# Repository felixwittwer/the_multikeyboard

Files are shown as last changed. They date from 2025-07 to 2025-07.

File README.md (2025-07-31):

<div align="center">



# the_multikeyboard

</div>

A custom keyboard that does it all. Standard keyboard, steno keyboard and macropad. It is a 115% keyboard that is a true alrounder. Besides all the features it excells your typing experience by having a slightly curved shape and some cool wrist rests that attatch magneticaly.

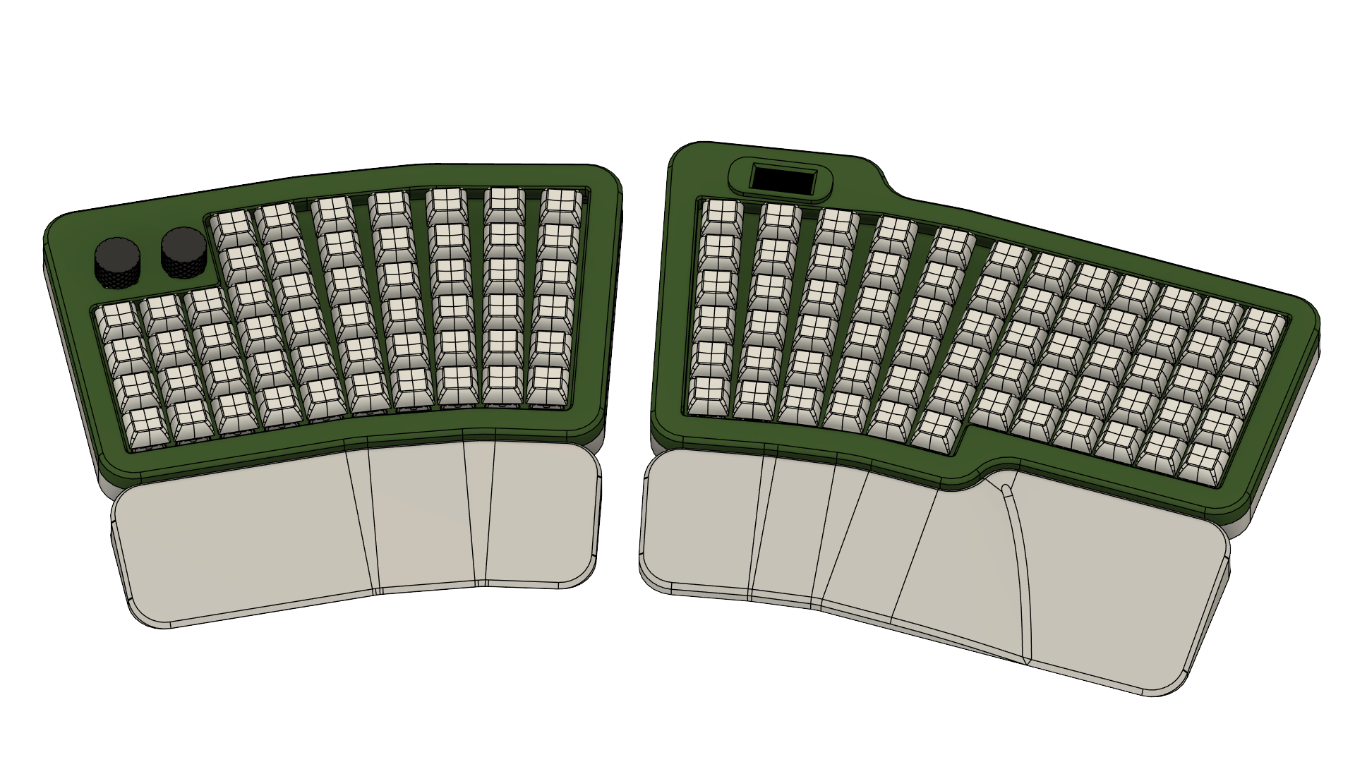
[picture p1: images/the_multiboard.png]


## About the project

I am actually someone that is currently learning steno myself and I already have a matching keyboard for that. Besides I also have a Macropad and of course a normal keyboard. You counted right I have three keyboards on my desk and this is bothering me. Thats why I decided to build my first own custom keyboard that combines all three. **THE MULTIKEYBOARD** is a keyboard that consists of a macropad (on the right side), a full sized keyboard (everything else :]) and a section in the middle that can be used for stenography typing.

[Look at some cool renders ](#renders) 

[... some CAD](#cad)

[... all the nice features](#features)

[... the PCB](#pcb-and-schematics)

[... the firmware](#firmware)

[... all the parst you need (BOM)](#bom)

## The project

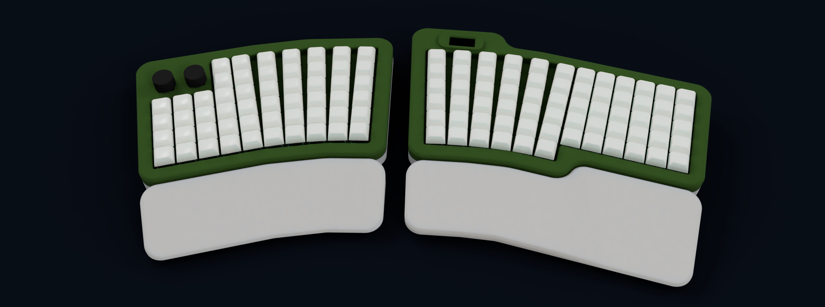
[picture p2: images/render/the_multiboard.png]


### Renders

<p float="left">
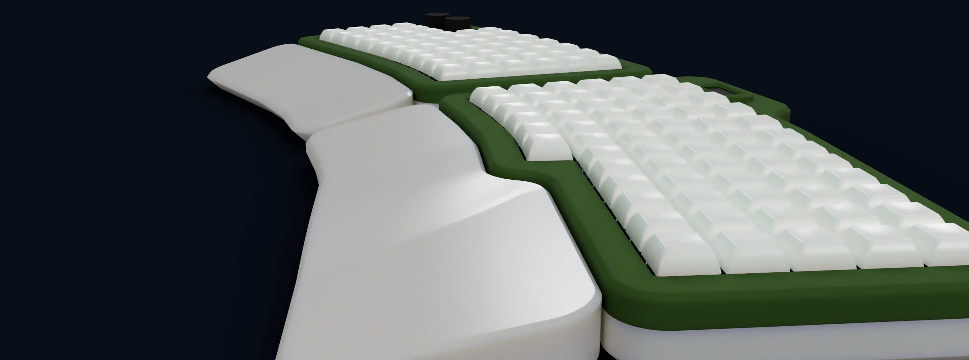
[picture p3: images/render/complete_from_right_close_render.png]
    
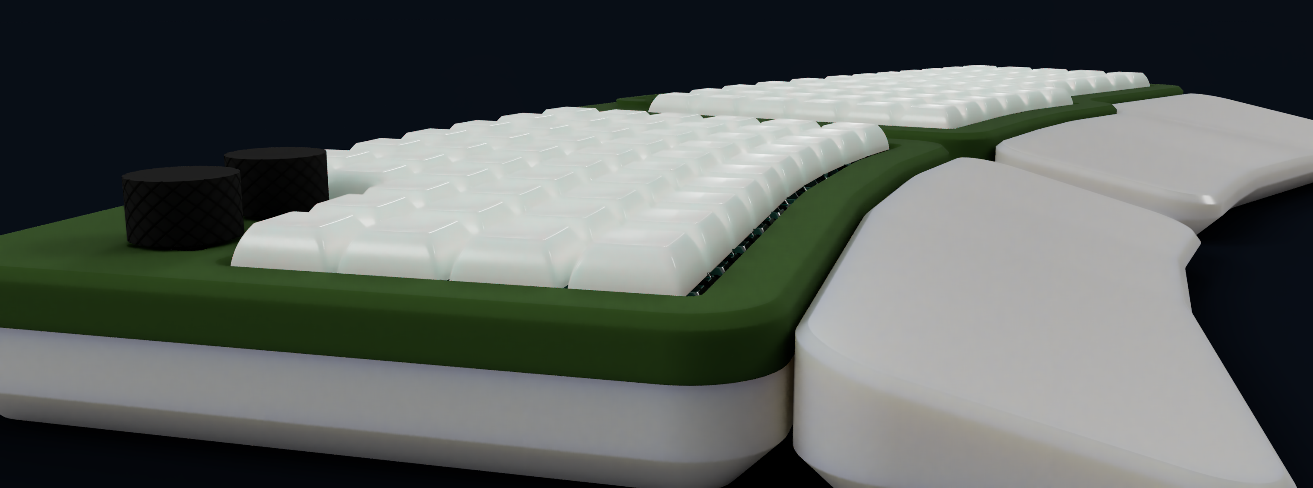
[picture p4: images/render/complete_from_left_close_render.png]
      
</p>
<p float="left">
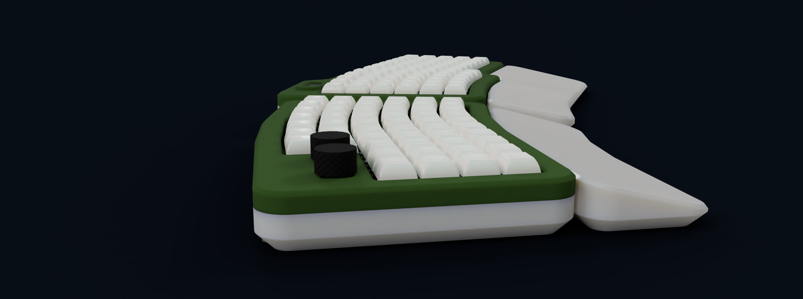
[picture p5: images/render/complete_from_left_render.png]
    
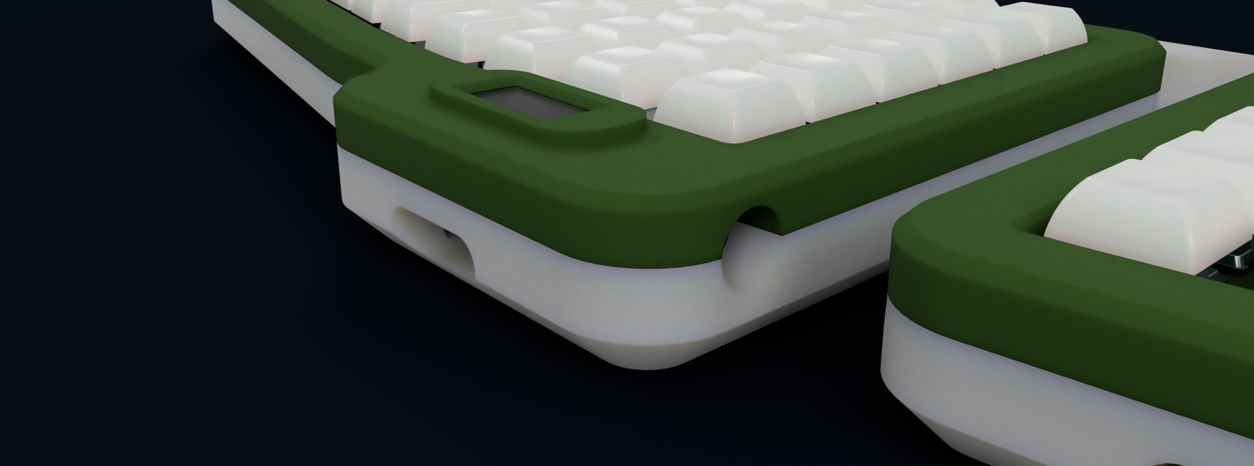
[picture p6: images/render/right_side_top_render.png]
    
</p>
<p float="left">
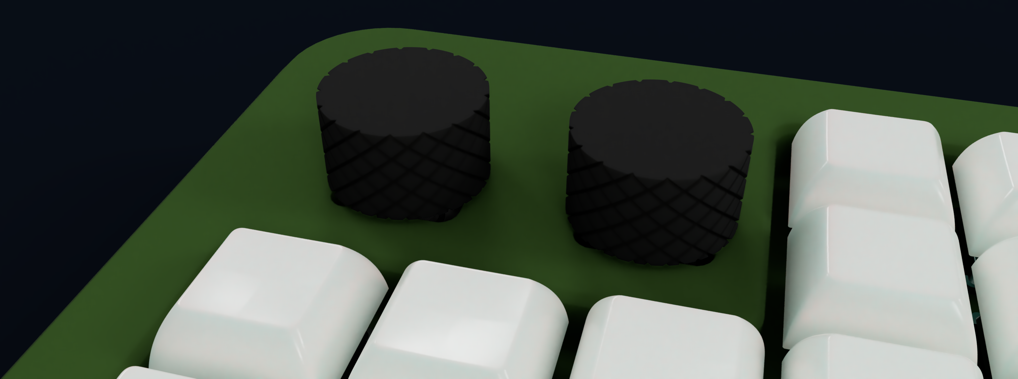
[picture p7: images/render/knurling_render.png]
    
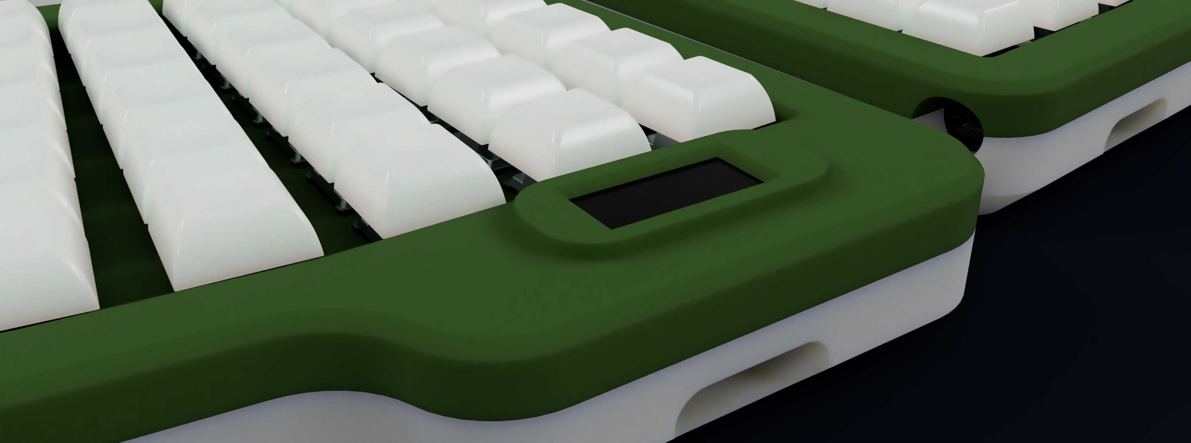
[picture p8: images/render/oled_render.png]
    
</p>

### CAD

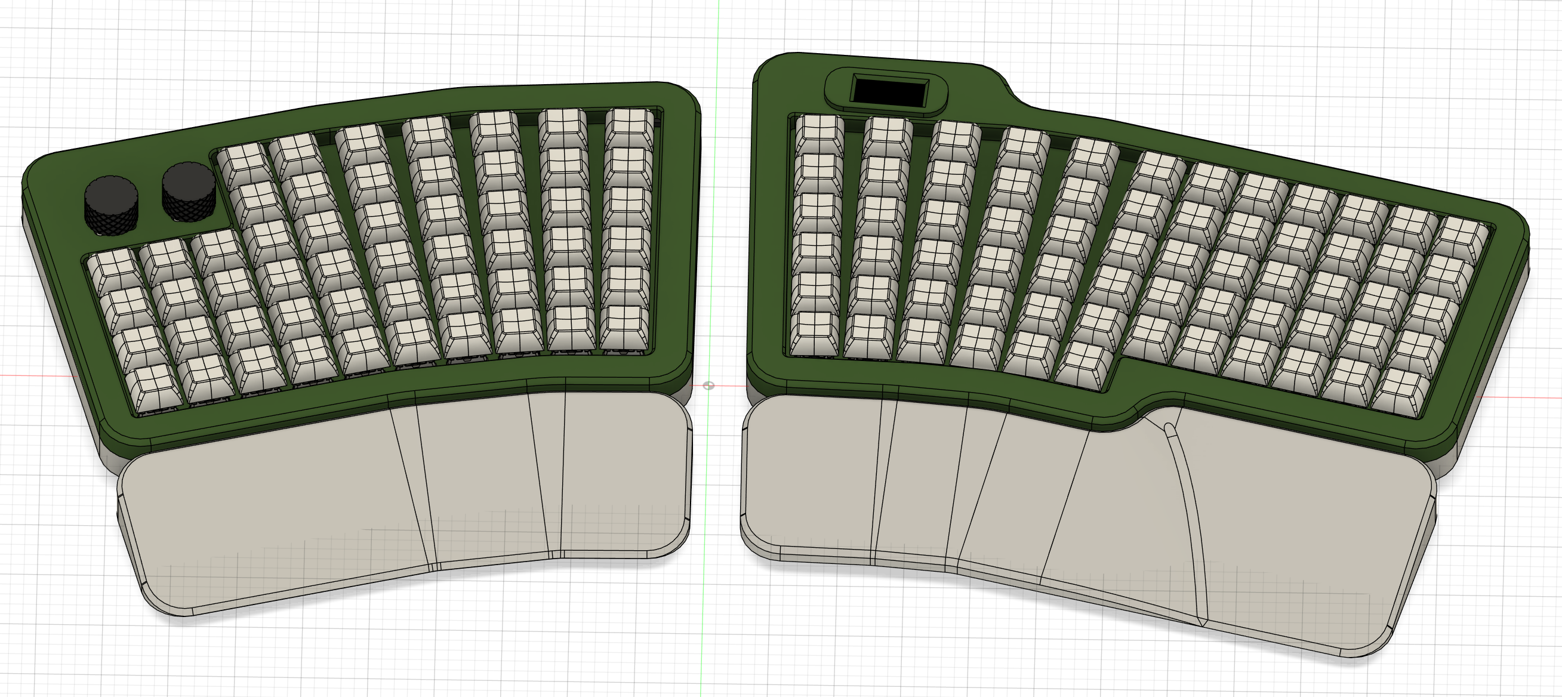
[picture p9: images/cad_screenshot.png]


### Features

**magnetic wrist rest**

Magnets are getting pressed into their location on the keyboard side and get clamped down by the crews holding the top and bottom piece of the keyboard together. On the wrist rest side the magnets just get glued into place. This designvhoice was intentional. I knwo that it is possible to encase magntes by pausing your 3D printer and the resuming but the case is already difficula enough to print due to its size so I don't wanted to add another hurdel.

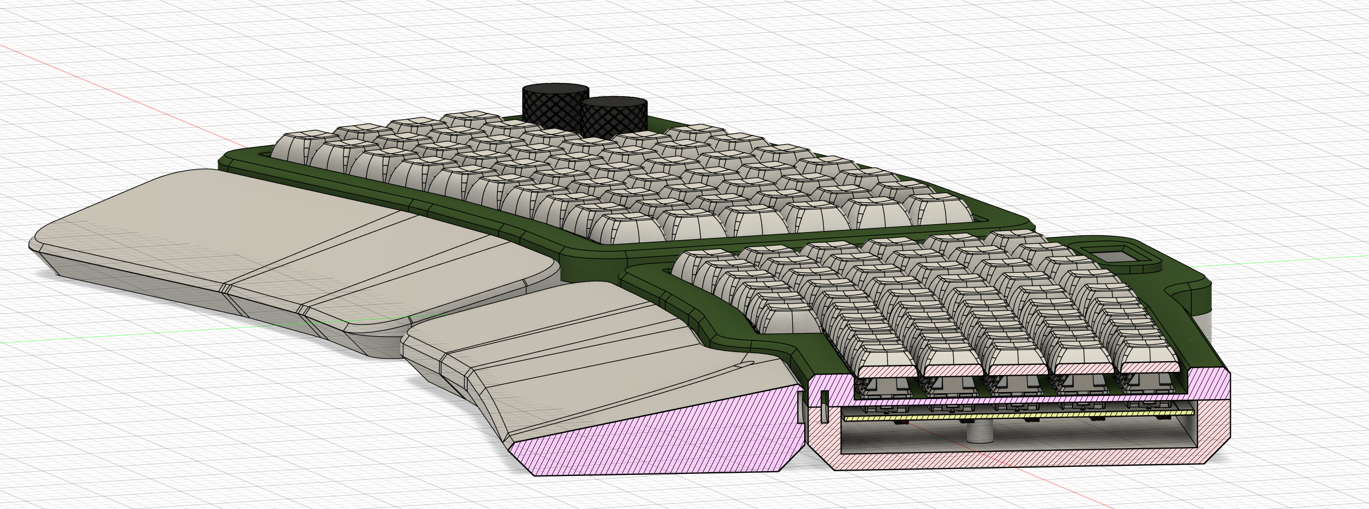
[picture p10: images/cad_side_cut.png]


**OLED**

The keyboard also has a small 0.91" OLED screen that tells you which layer you are currently using. In the future I will maybee add some small pixelart.

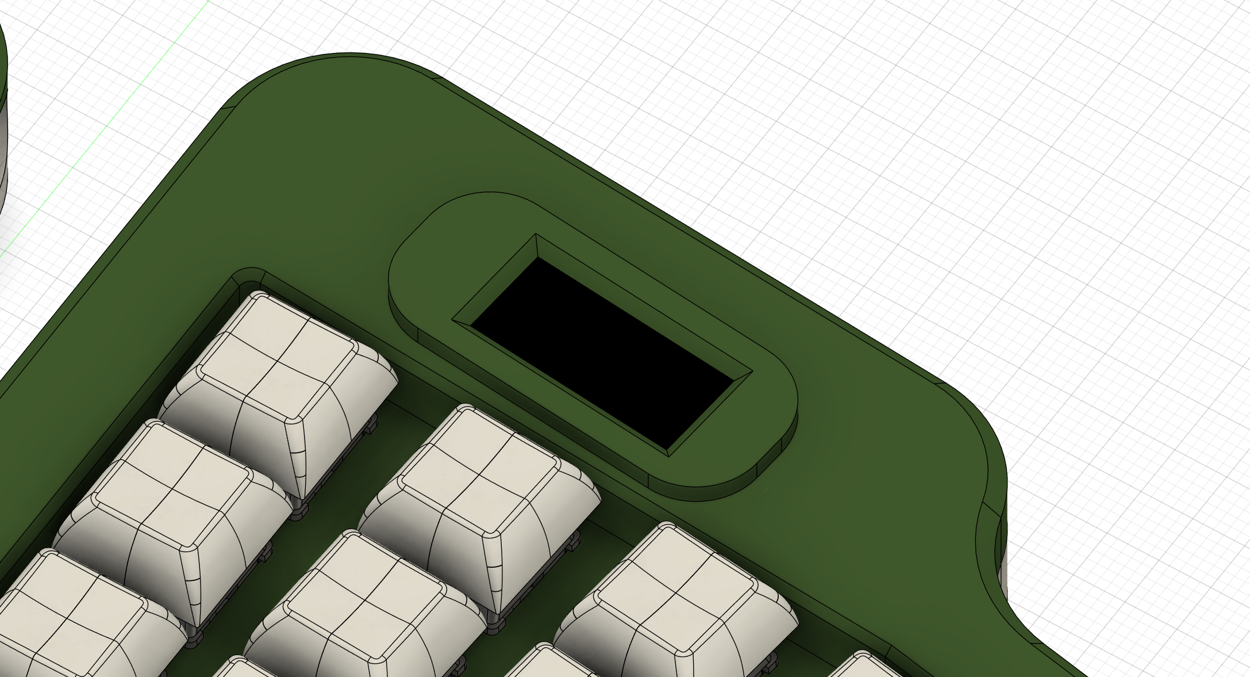
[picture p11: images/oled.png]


**dials with knurling**

The left side of the keyboard is basically a macropad with 16 kustomizable keys and two rotary encoders witha custom dial. The knurling on the dials is probably going to feel amazing.

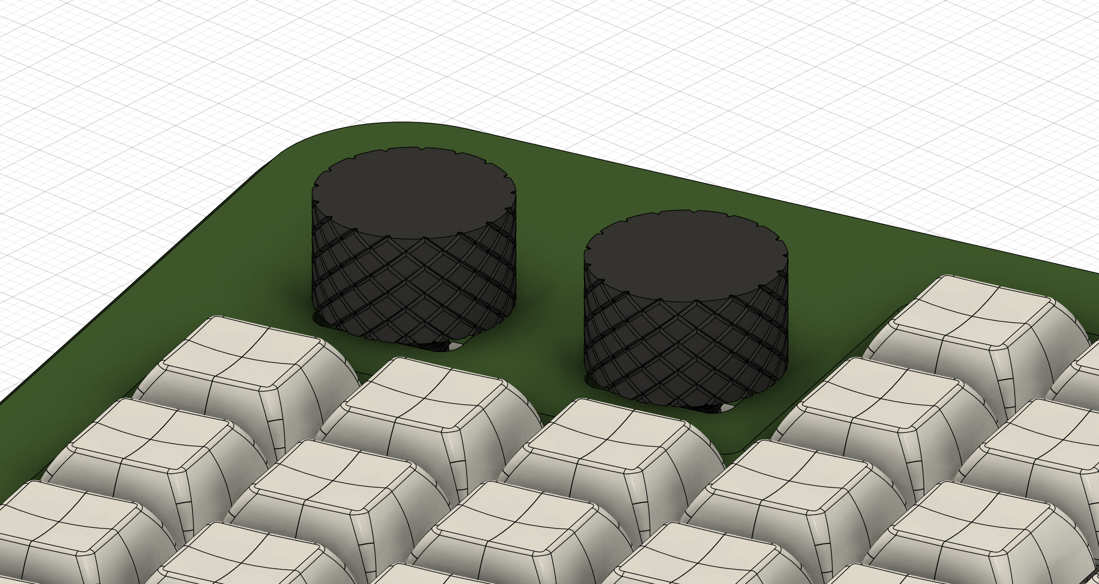
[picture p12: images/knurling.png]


**steno capabilities**

I intentionally designed the kyboard to be steno capable and also have a layout that could fita steno keyboard.

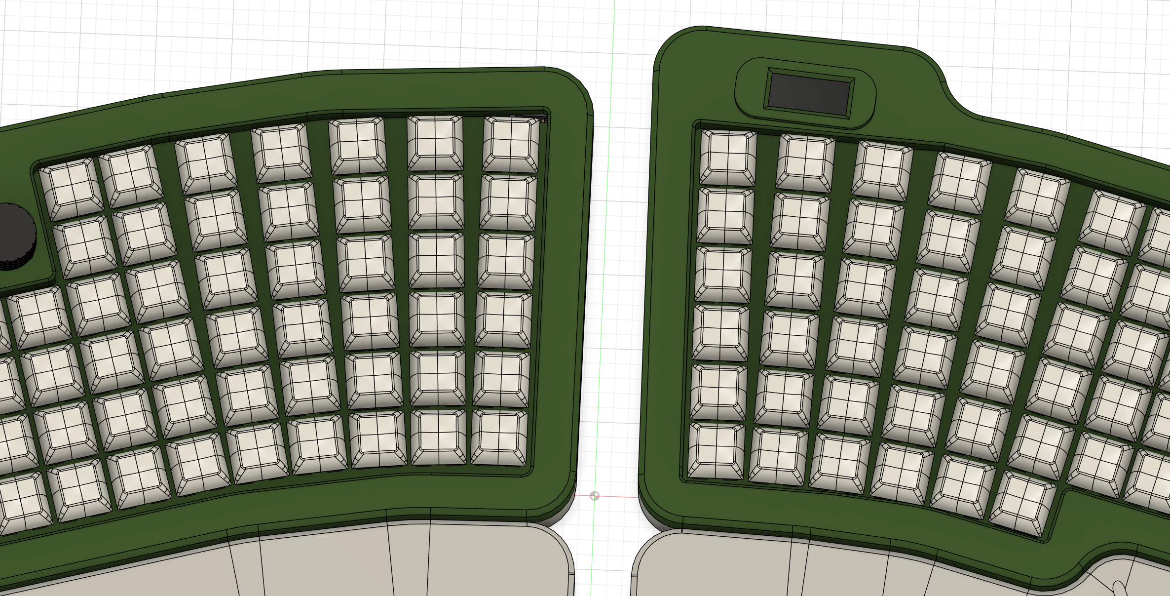
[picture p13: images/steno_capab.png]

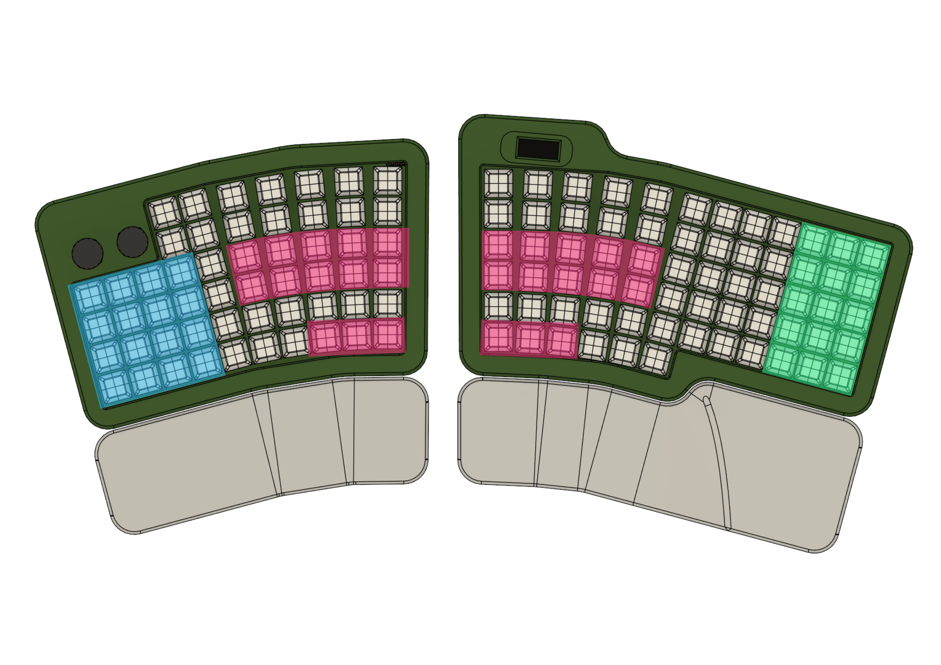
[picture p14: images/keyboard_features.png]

(blue -> macropad, magenta -> steno, green -> numpad)

### PCB and schematics

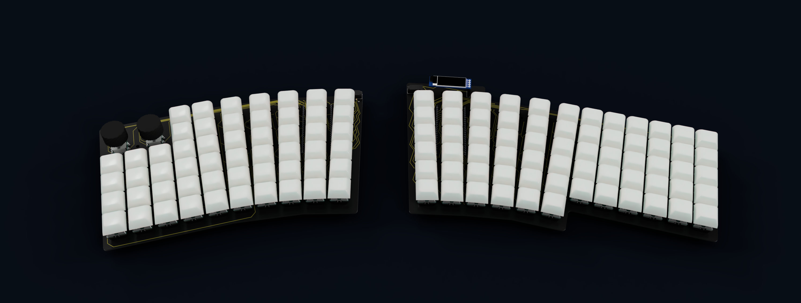
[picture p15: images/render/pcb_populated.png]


<p float="left">
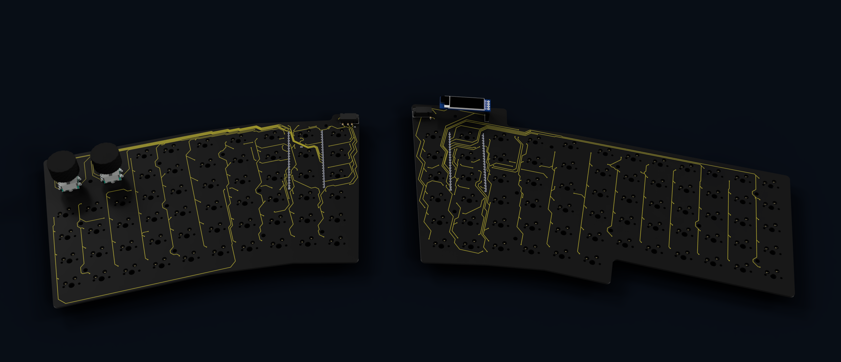
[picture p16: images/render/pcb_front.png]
    
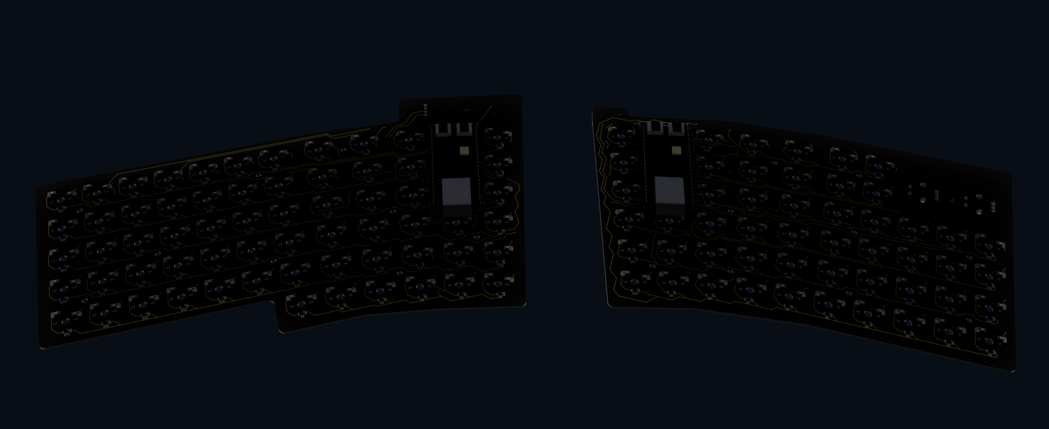
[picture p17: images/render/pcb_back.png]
    
</p>

<p float="left">
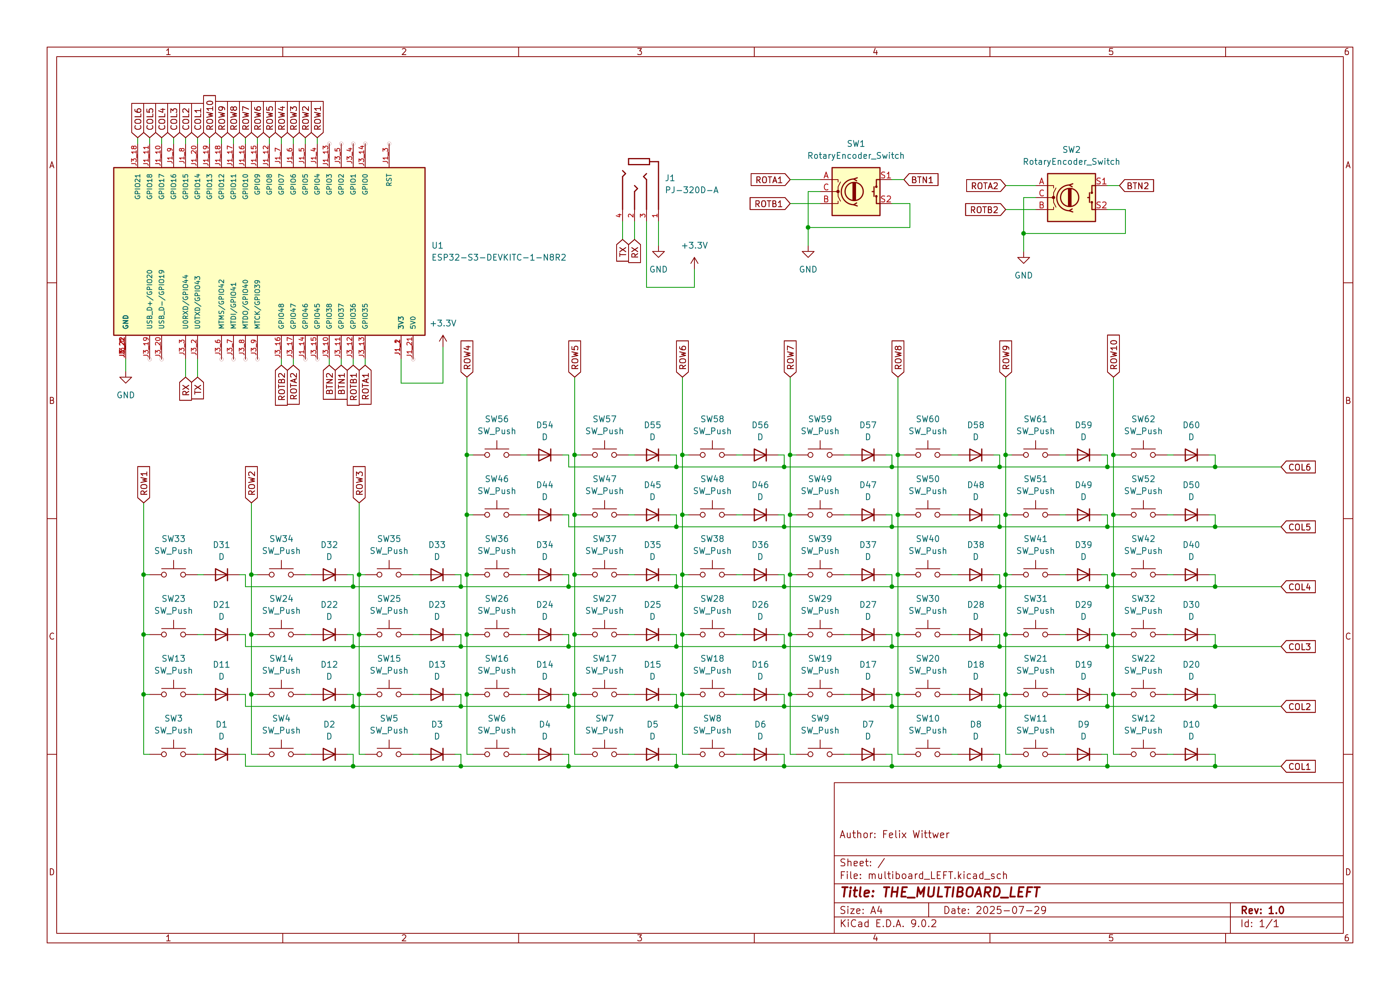
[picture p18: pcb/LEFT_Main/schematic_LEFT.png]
  
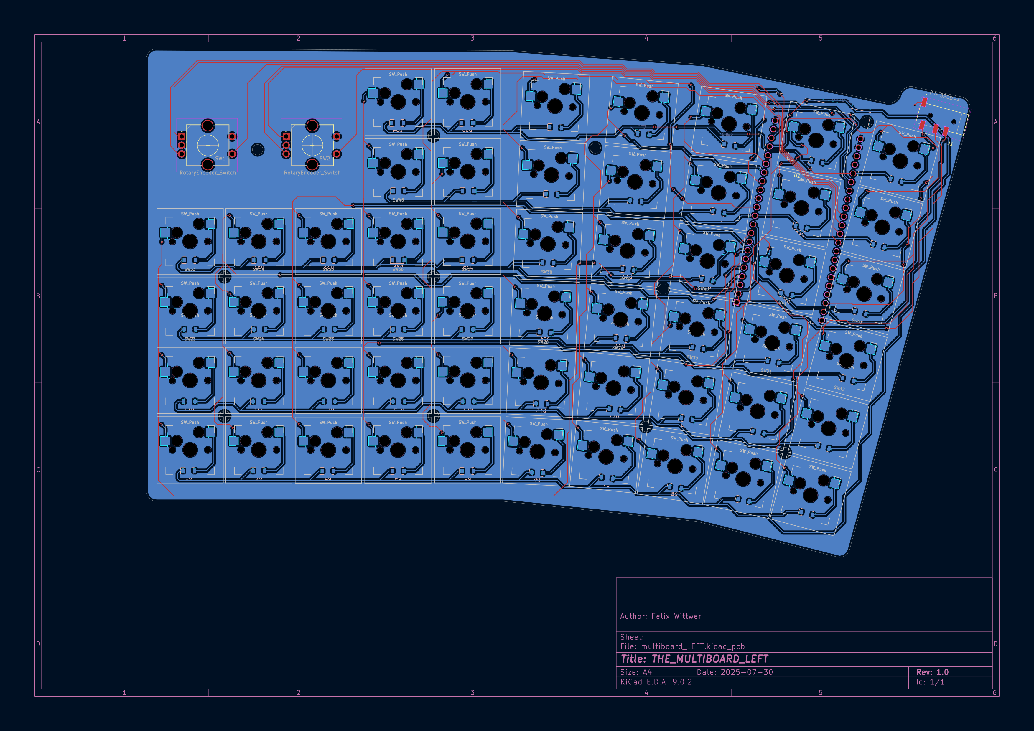
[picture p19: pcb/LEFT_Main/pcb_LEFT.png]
  
</p>

<p float="left">
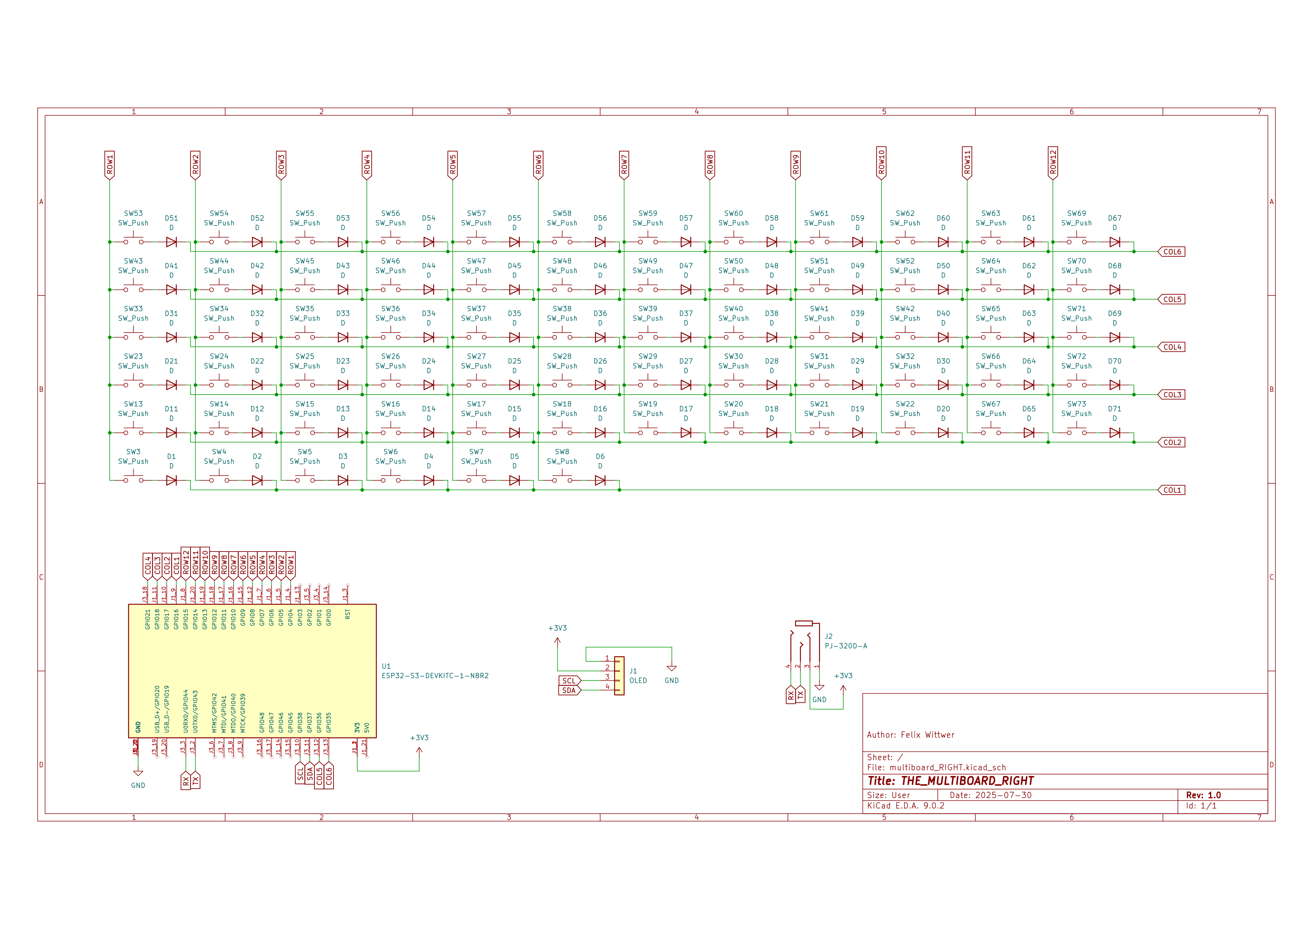
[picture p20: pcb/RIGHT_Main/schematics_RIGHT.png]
  
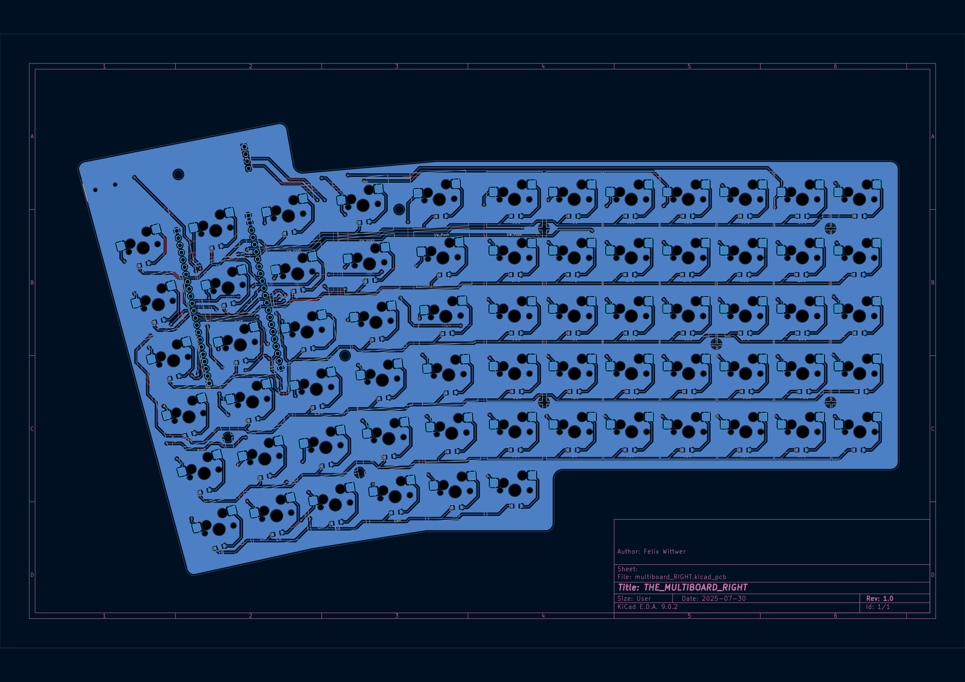
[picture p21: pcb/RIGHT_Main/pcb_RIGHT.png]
  
</p>

## Firmware

The keyboard is running KMK have a look [here](/firmware/).

## BOM

**sum: 79.67 USD**

| part name | amount | price | link | note |
| --- | --- | ----- | ---- | ---- |
| Rotary encoder EC24 | 2 | 1.32 USD | https://de.aliexpress.com/item/1005006894514858.html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 | look out for the EC numer it is importent for the resolution of the encoder 
| Keyswitches | 120 (54+66) | 21.12 USD | https://de.aliexpress.com/item/1005006091988869.html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
| Keycaps | 120 (54+66) | 7.88 USD| https://de.aliexpress.com/item/32842379355.html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 | please look where you can buy matching quantities 120 Keys is larger than normal keyboard size
| hotswap socets | 120 (54+66) | 12.92 USD | https://de.aliexpress.com/item/1005007476614771.html?gatewayAdapt=glo2deu | ---- |
| diodes SOD-123 | 120 (54+66) | 2.74 USD | https://de.aliexpress.com/item/1005004664827360.html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 | ---- |
| headphone jack | 2pcs | 1.16 USD | https://de.aliexpress.com/item/4000661908135.html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 | ---- |
| magnets 10mmx2mm | 8 | 1.16 USD | https://de.aliexpress.com/item/1005009238165372.html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 | ---- |
| ESP32-S3 | 2 | 15.12 USD | https://de.aliexpress.com/item/1005008209644199.html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 | ---- |
| 0.96" OLED | 1 | 1.16 USD | https://de.aliexpress.com/item/1005006153887805.html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 | ---- |
| PCB LEFT Main | 1 | ~ 5 USD |  https://jlcpcb.com/ | price is subject to JLCs review |
| PCB RIGHT BACK | 1 | ~ 5 USD |  https://jlcpcb.com/ | price is subject to JLCs review |
| | total | 74.67 + (shipping ~5 USD) **79.67 USD** | 

**sum: 79.67 USD**

## Credits

**Thanks for the detailed 3D models!**

Gateron keyswitch 3D model: https://www.gateron.com/pages/3d

Keycap 3D model: https://grabcad.com/library/dsa-keycap-for-cherry-mx-switches-1

ESP32-S3 (before I modified it): https://grabcad.com/library/esp32-s3-module-for-pcb-preview-1

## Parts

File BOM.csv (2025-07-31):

part name | amount | price | link | note
Rotary encoder EC24 | 2 | 1.32 USD | https://de.aliexpress.com/item/1005006894514858.html?utparam-url=scene%3Asearch%7Cquery_from%3A | look out for the EC numer it is importent for the resolution of the encoder
Keyswitches | 120 (54+66) | 21.12 USD | https://de.aliexpress.com/item/1005006091988869.html?utparam-url=scene%3Asearch%7Cquery_from%3A
Keycaps | 120 (54+66) | 7.88 US | https://de.aliexpress.com/item/32842379355.html?utparam-url=scene%3Asearch%7Cquery_from%3A | please look where you can buy matching quantities 120 Keys is larger than normal keyboard size
hotswap socets | 120 (54+66) | 12.92 USD | https://de.aliexpress.com/item/1005007476614771.html?gatewayAdapt=glo2deu | ----
diodes SOD-123 | 120 (54+66) | 2.74 USD | https://de.aliexpress.com/item/1005004664827360.html?utparam-url=scene%3Asearch%7Cquery_from%3A | ----
headphone jack | 2pcs | 1.16 USD | https://de.aliexpress.com/item/4000661908135.html?utparam-url=scene%3Asearch%7Cquery_from%3A | ----
magnets 10mmx2mm | 8 | 1.16 USD | https://de.aliexpress.com/item/1005009238165372.html?utparam-url=scene%3Asearch%7Cquery_from%3A
ESP32-S3 | 2 | 15.12 USD | https://de.aliexpress.com/item/1005008209644199.html?utparam-url=scene%3Asearch%7Cquery_from%3A | ----
0.96" OLED | 1 | 1.16 USD | https://de.aliexpress.com/item/1005006153887805.html?utparam-url=scene%3Asearch%7Cquery_from%3A | ----
PCB LEFT Main | 1 | ~ 5 USD | https://jlcpcb.com/ | price is subject to JLCs review
PCB RIGHT BACK | 1 | ~ 5 USD | https://jlcpcb.com/ | price is subject to JLCs review
 | total | 79.67 USD

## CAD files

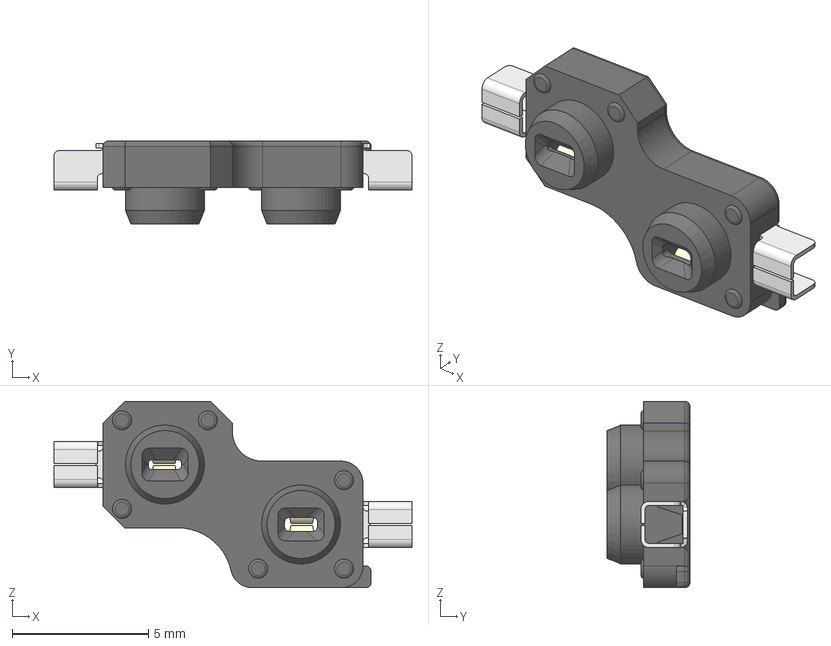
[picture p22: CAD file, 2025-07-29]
pcb/LEFT_Main/multiboard_LEFT/MX_V2-main/3D/Kailh-Choc-Socket-CPG135001S30.step
13.1 x 3.05 x 6.85 mm
Insert 2
Insert 1

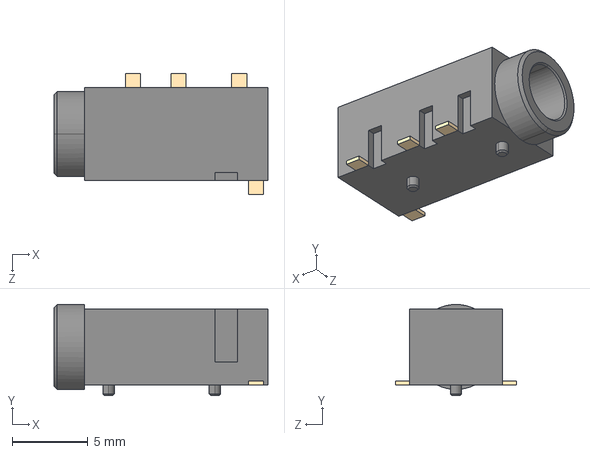
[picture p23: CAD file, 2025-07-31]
pcb/LEFT_Main/multiboard_LEFT/PJ-320D-A/PJ-320D-A.step
14.1 x 6.00 x 8.00 mm

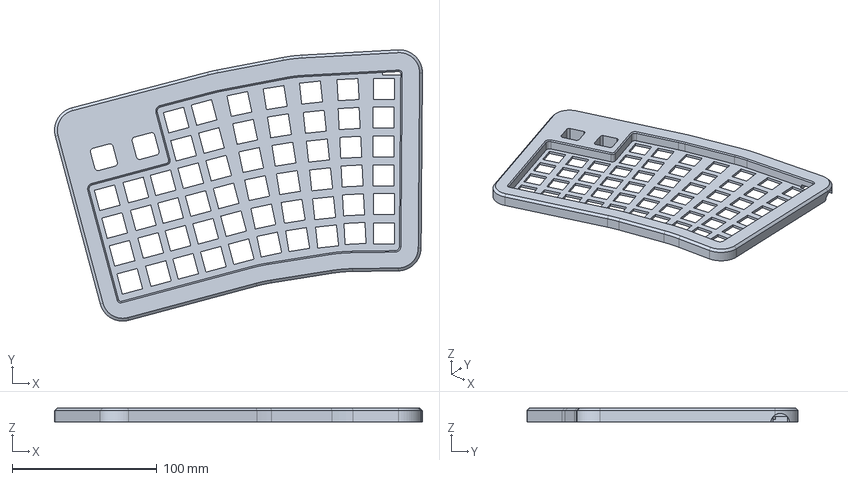
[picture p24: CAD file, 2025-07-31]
production/case/right_top.step
254.2 x 187.5 x 10.0 mm

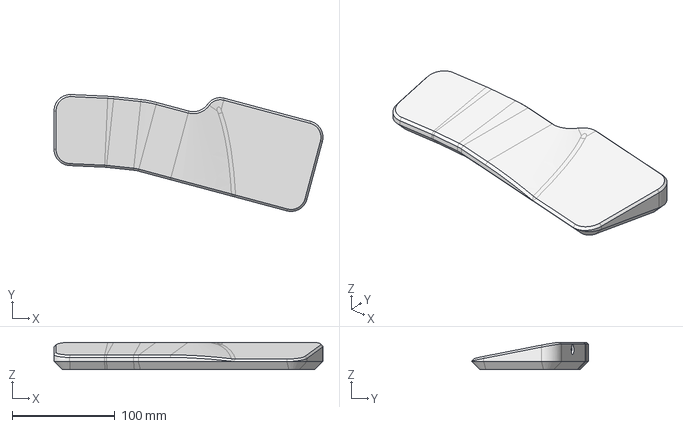
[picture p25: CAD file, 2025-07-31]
production/wrist_rest/right_rest.step
261.2 x 113.5 x 26.6 mm

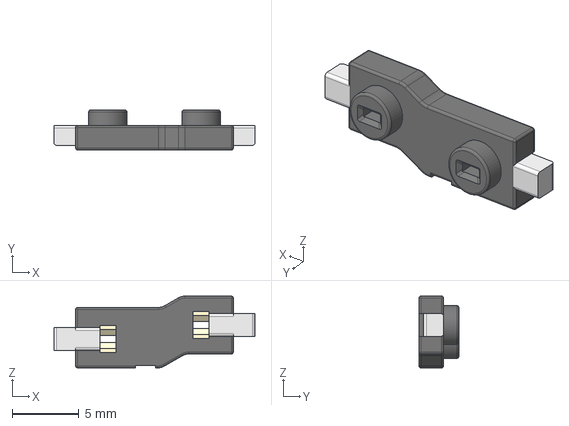
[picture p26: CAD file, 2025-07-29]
pcb/LEFT_Main/multiboard_LEFT/MX_V2-main/3D/Gateron-KS33-Socket.step
15.1 x 3.00 x 5.40 mm

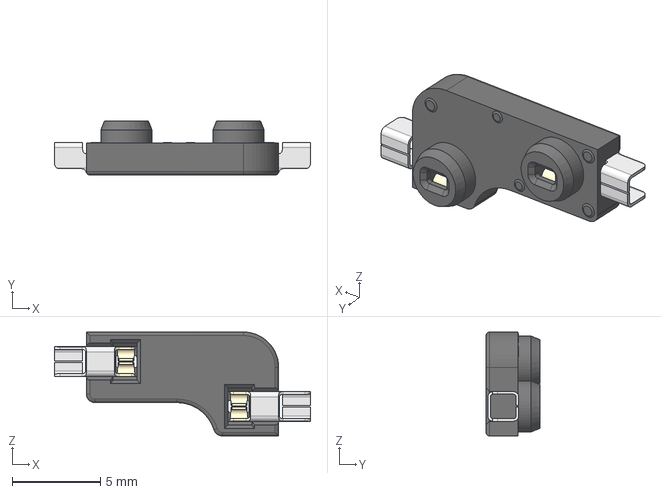
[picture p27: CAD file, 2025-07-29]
pcb/RIGHT_Main/multiboard_RIGHT/MX_V2-main/3D/MX-Hotswap-Socket.step
14.5 x 3.05 x 5.89 mm

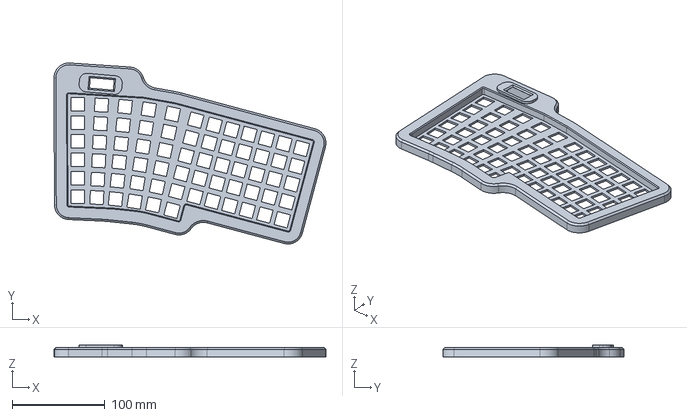
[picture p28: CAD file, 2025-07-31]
production/case/left_top.step
293.1 x 195.1 x 12.5 mm

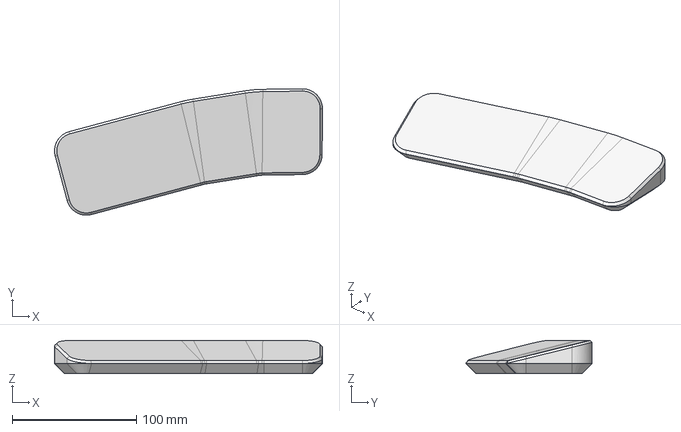
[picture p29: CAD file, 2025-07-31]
production/wrist_rest/left_rest.step
215.4 x 101.6 x 26.5 mm

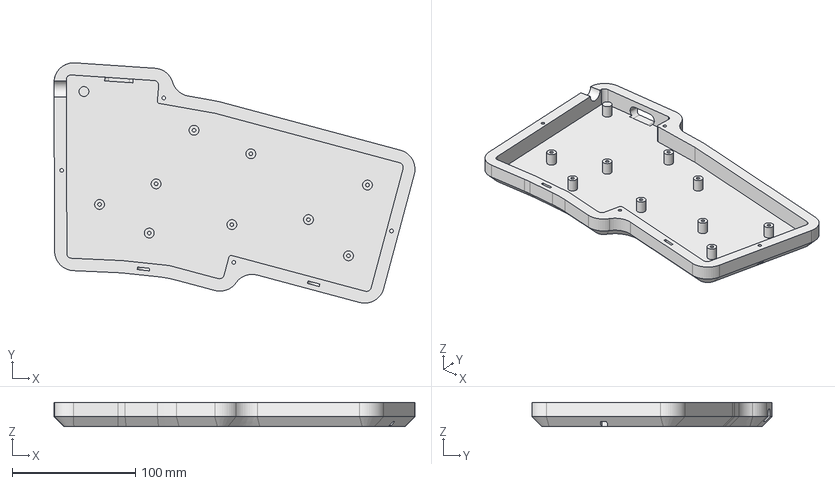
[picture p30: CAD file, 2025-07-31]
production/case/right_bottom.step
293.1 x 195.1 x 19.5 mm

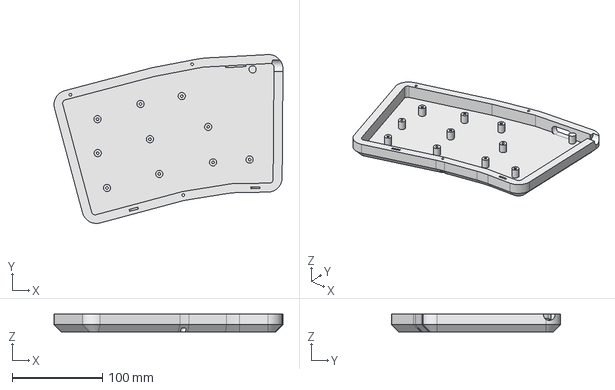
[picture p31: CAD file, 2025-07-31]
production/case/left_bottom.step
254.2 x 187.5 x 19.5 mm

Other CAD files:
production/case/left_bottom.stl
production/case/left_top.stl
production/case/right_bottom.stl
production/case/right_top.stl
production/wrist_rest/left_rest.stl
production/wrist_rest/right_rest.stl

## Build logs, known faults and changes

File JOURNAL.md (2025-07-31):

---
title: "The Multikeyboard"
author: "Felix Wittwer (fegolix)"
description: "A split keyboard that can be a keyboard, macropad and steno keyboard at the same time"
created_at: "2024-07-29"
---

# Journal

Here you can see a documentation of the entire development process.

**Total hours spent: 25h**

## July 29th (4h)

### Session 1 (2h) planing and layout

As a starting point for my custom split keyboard I decided to take some rough measurements of my hand an arrange the keys over it inside Inkscape. I decided on going with a full sized layout with the addition of a macropad and two rotary encoders on the left side. As someone who is coding on a daily bases it was important for me to have a full sized Layout and all the functions keys. If I decide that I do not need the numpad on the right side it can be easealy turned into a second macropad as on the left. For the microcontroler I decided on going with two ESP32-S3s because I use them a lot and they are relatively cheap. Besides that most dev boards also provide two USB ports so I can link them together in teh future via a simple USB C cable. I mean the plan is wireless but to make it futureproof. Pesides that I have lots of GPIO and enough computational power for running the firmware. (Plover for Steno might not be that easy to integrate)

<p float="left">
  
  
</p>

### Session 2 (2h) schematics LEFT

I now started creating the schematics for the LEFT side. Schematic is now done and I can start with designing the PCB. I think it is probably smart to design the PCB for the left side first and the copy the PCB and use it for the right side. So later on I only need to make few changes to the schematic and the PCB is almost finished for the right side. I will probably need to make 4 PCBs or more to also be like the front and backplate of the keyboard. The housing then will be pretty minimal. I mean I kind of like the look of it but we will see.



## July 30th (10h)

### Session 1 (4h) creating left PCB

Getting everything placed where I wanted took some time and until now I also havent fogured out how to rotate multiple elements in KiCad with a specific angele so rotating stuff also took a while :). Due to rotating the footprints for the keyswitches I was also abte to fit the ESP on teh back side of the board without needing to make the PCB even bigger than it already is.

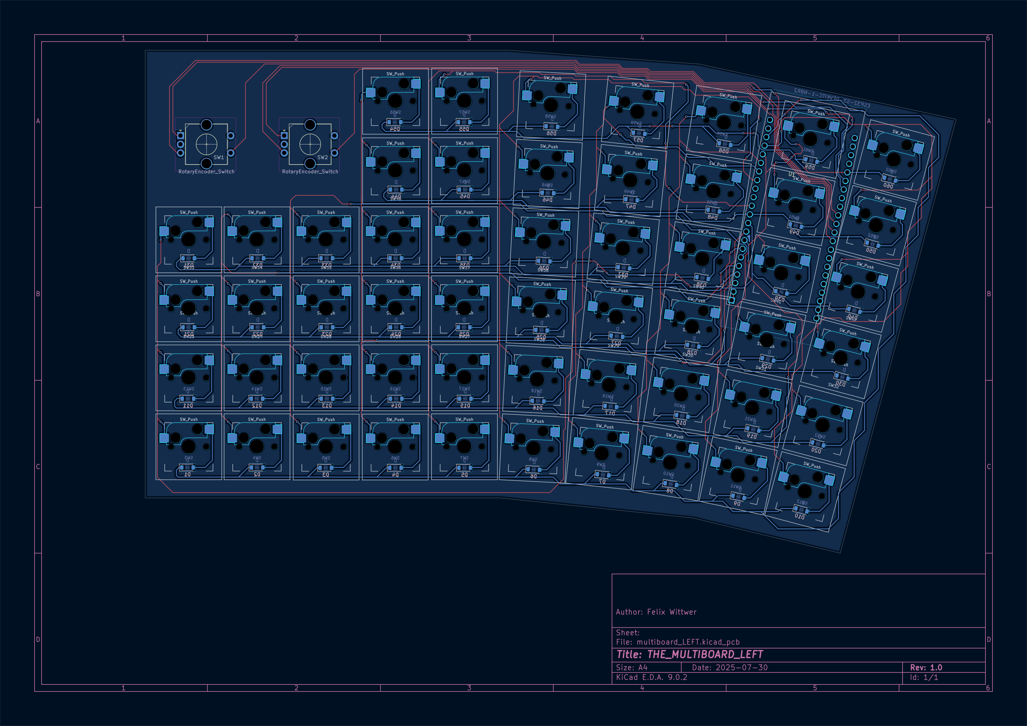
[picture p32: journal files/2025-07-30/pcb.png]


### Session 2 (6h) finishing left and right main PCBs

I have now succesful finised creating the left and right PCBs. I was actually speedrunning the right side until I noticed that the ESP32 was wrongly mirrored so I needed to redo most of the routing. So in the end it took almost the same thime even a bit longer that the left side. Because my PCBs are relatively large I am not going to design a 3D printed housing becuse it somply wouldn't fit into my 3D printers build volume. I am instead going for a PCB "sandwitch" wit three PCBs per side. The main ones are already finished but I now need backplates and a front plate that is also going around the keyswitches.

<p float="left">
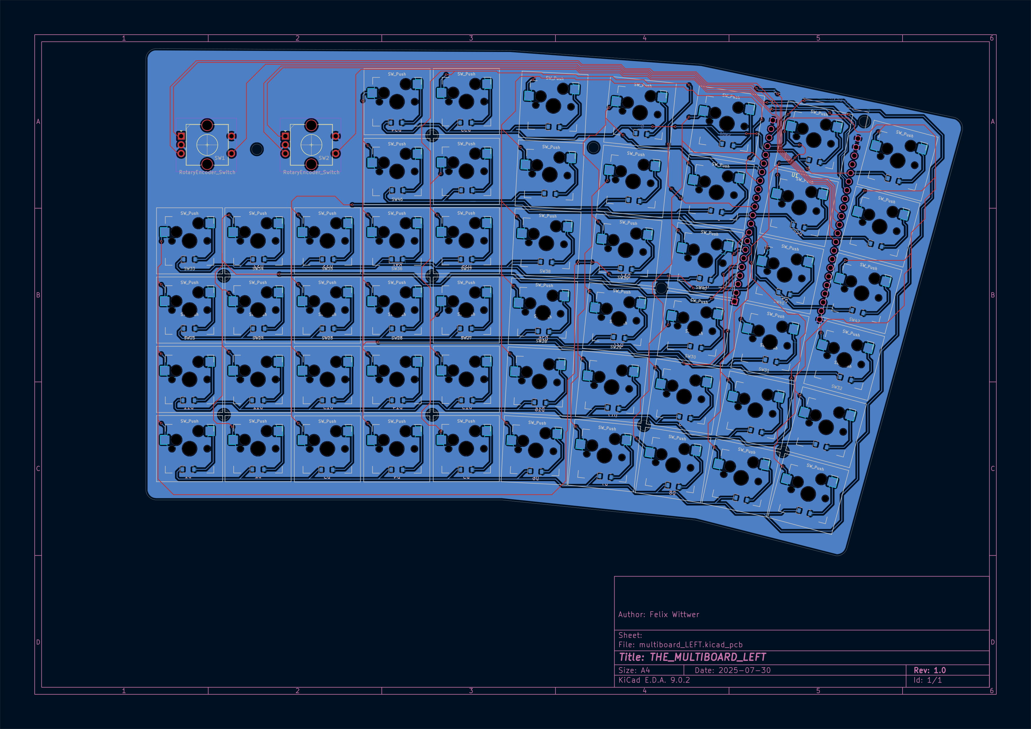
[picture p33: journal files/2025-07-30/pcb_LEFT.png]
  
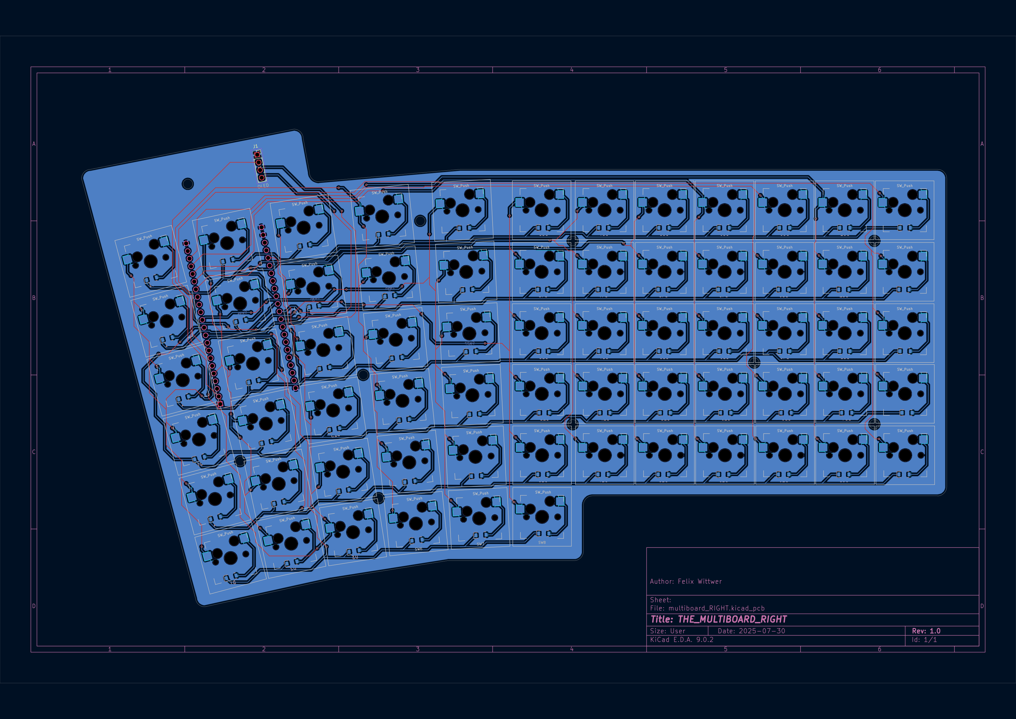
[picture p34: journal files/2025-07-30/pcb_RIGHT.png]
  
</p>

<p float="left">
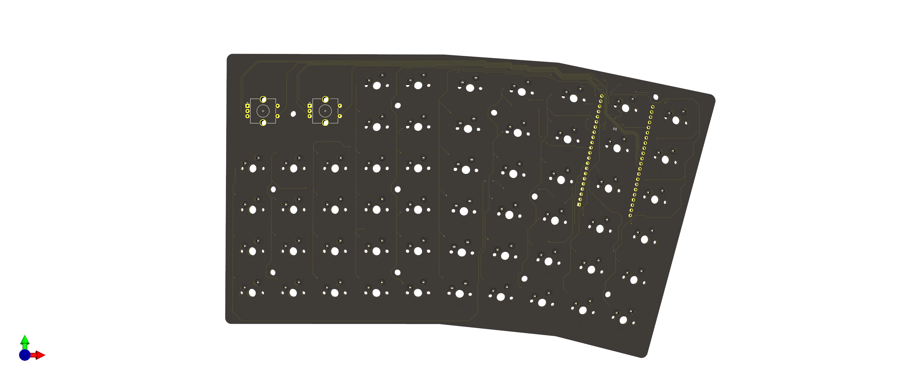
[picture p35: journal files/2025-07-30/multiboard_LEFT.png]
  
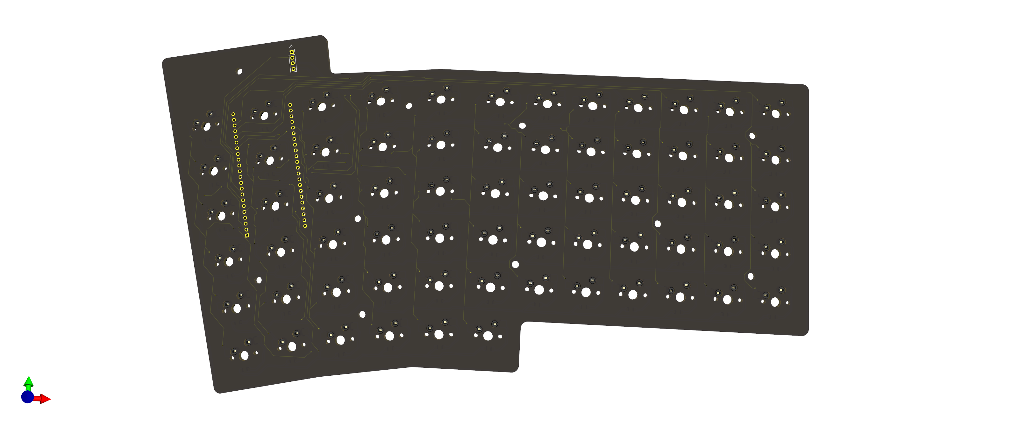
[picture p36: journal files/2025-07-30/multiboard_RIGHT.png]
  
</p>

### Session 3 (30m) researching parts, creating BOM

I have just finished reasearching some parts and searching for cheap components on Aliexpress. I also had the idea of actually doing two seperate design cause the case is probably getting really big and not everybody has a printer with such a buildvolume at home.

## July 31st (6h)

### 

Finally finished with designing the case and placing all the components of the keyboard where they belong. Placing 120 keyswitches wasn't the best task in the world but at least in some areas I could arrange them in a normal rectengular grid. To make my keyboard a bit more special I decided to add some handrests which attach magnetically. I designed it in such a way that the magntes can bee added after printing the case so that you dont have to stop your print in insert them but rather do that later.

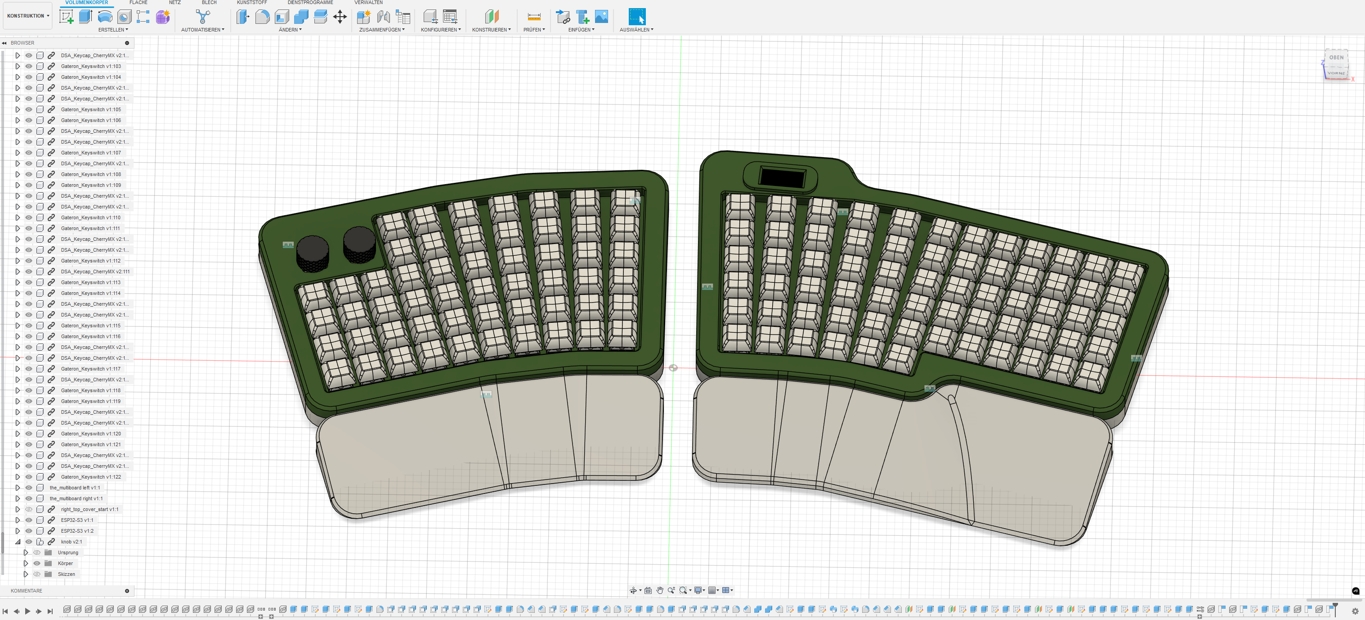
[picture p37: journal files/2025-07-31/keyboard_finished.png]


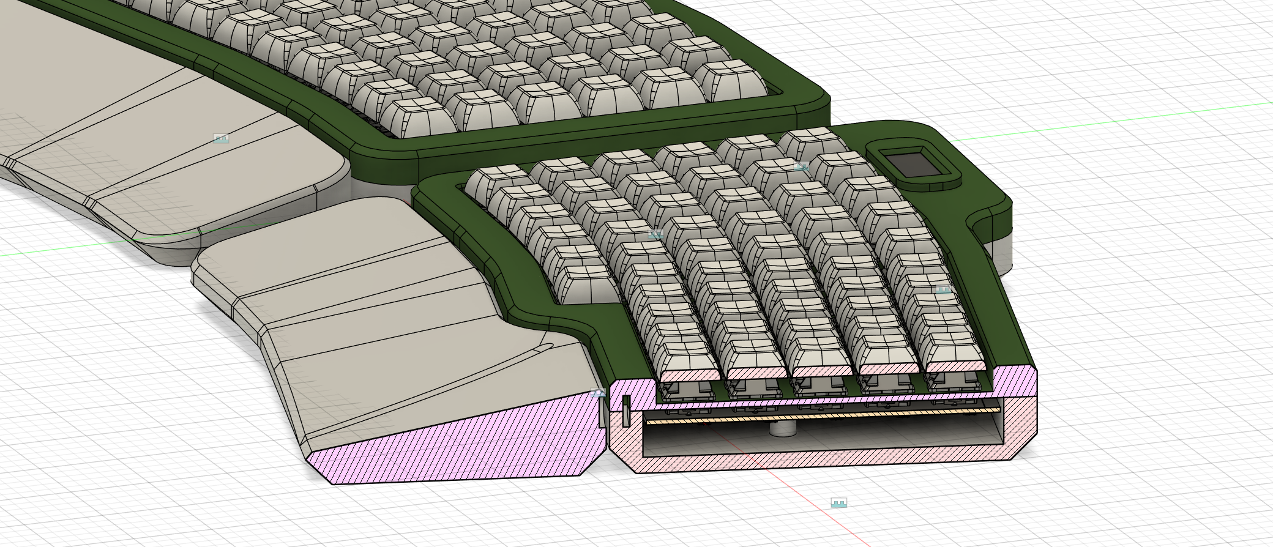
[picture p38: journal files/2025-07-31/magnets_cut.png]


### Session 2 (3h) firmware time

I decieded on going with KMK because it is realatively simpe and also supports steno. So it is perfect for my project. 

Writing the actual firmware turned out to be a bit more diffcult than I thought because I have multiple layers on the ekyboard and steno isnT# usual on most keyboards. besides that I also needed to integrate the macro functionality on the left side.

As of now there will be one key near the macro part that toggles between normal and steno mode. I also noticed that using the second usb port of the esp32-S3 isn't uspported by KMK natively so I need to modify the PCB a bit to have somethign like a beadphone jack to connect both sides via uart.

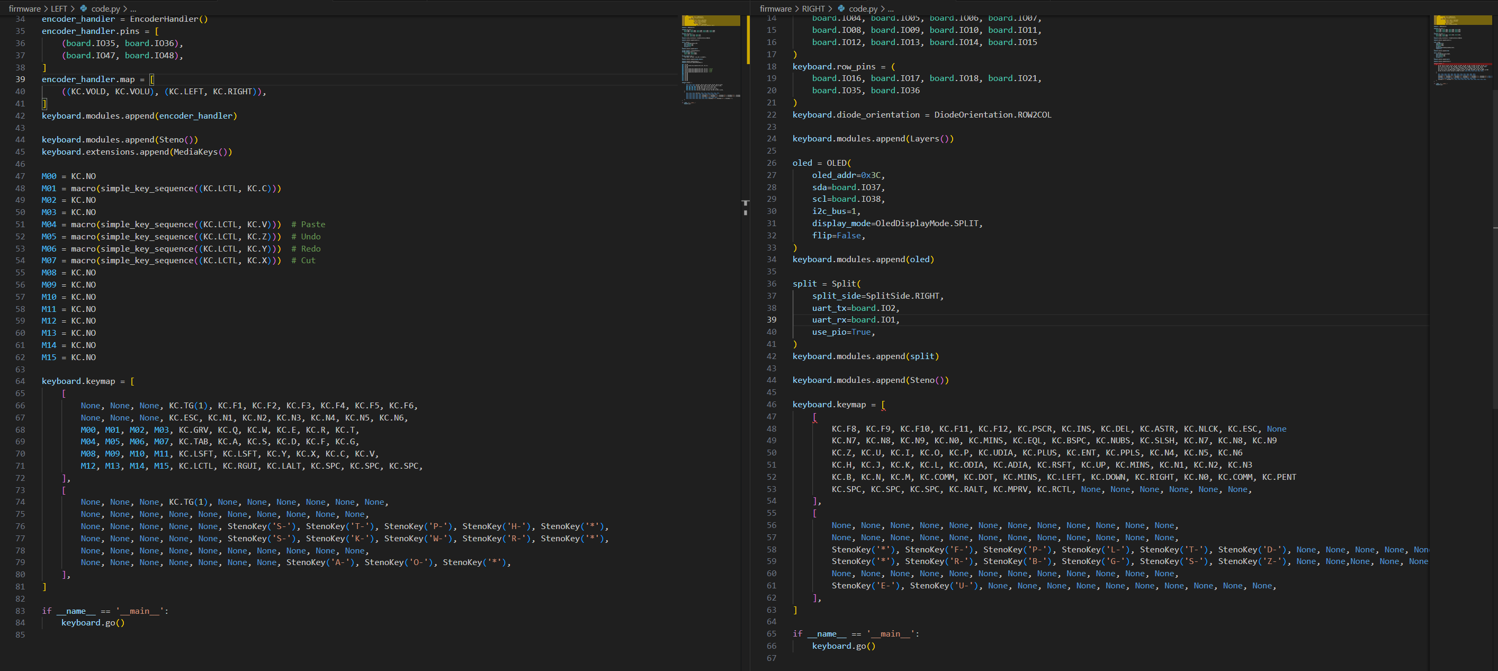
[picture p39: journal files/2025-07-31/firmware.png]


### Session 3 (1h 30m) fixing the pcbs and cad

Adding a headphone jack wasn't as straigtforward as I though. First of all I needed to find matching schematics and also wanted to keeb the PCB shape the same so I don't have to do much ework on the case say so there needed to be done something on the shape.

In the end a got it working and got it also integrated into my existing CAD model. I think it looks got for beeing retrofited afterwards.

<p float="left">
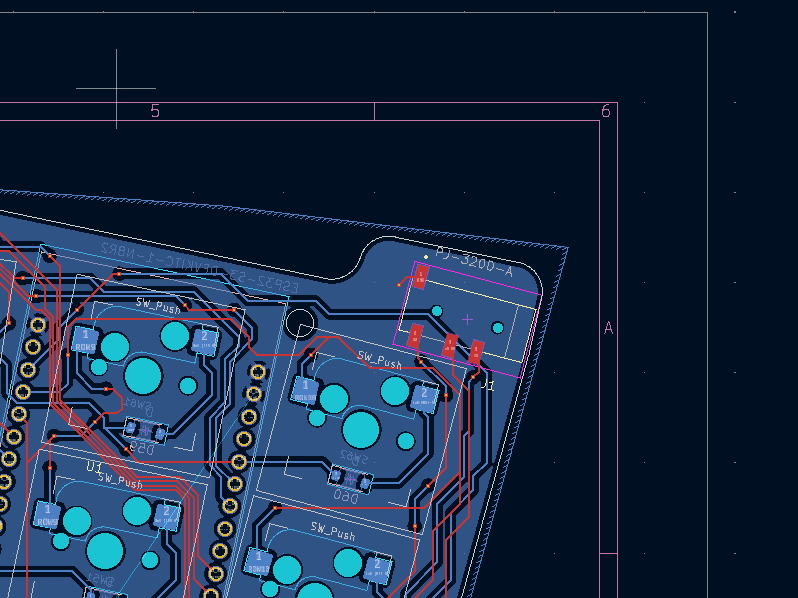
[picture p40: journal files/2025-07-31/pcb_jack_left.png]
  
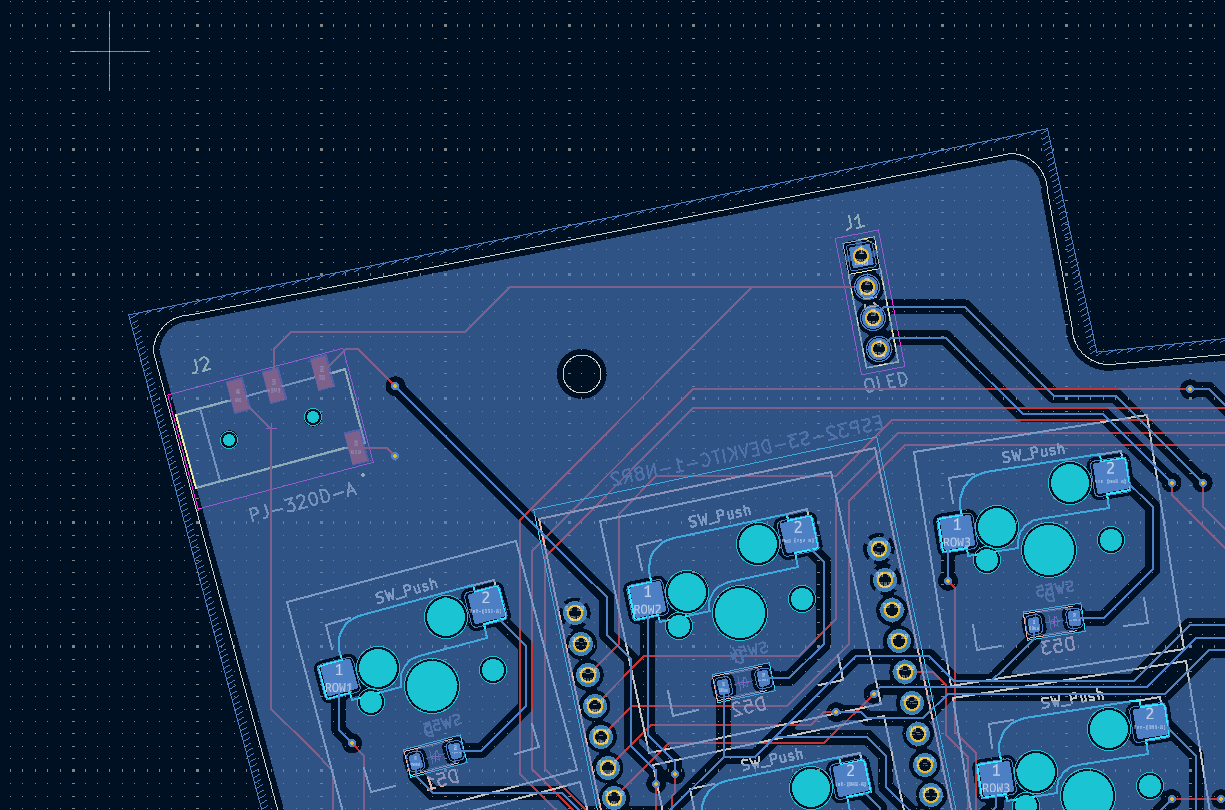
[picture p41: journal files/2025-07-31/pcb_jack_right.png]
  
</p>

<p float="left">
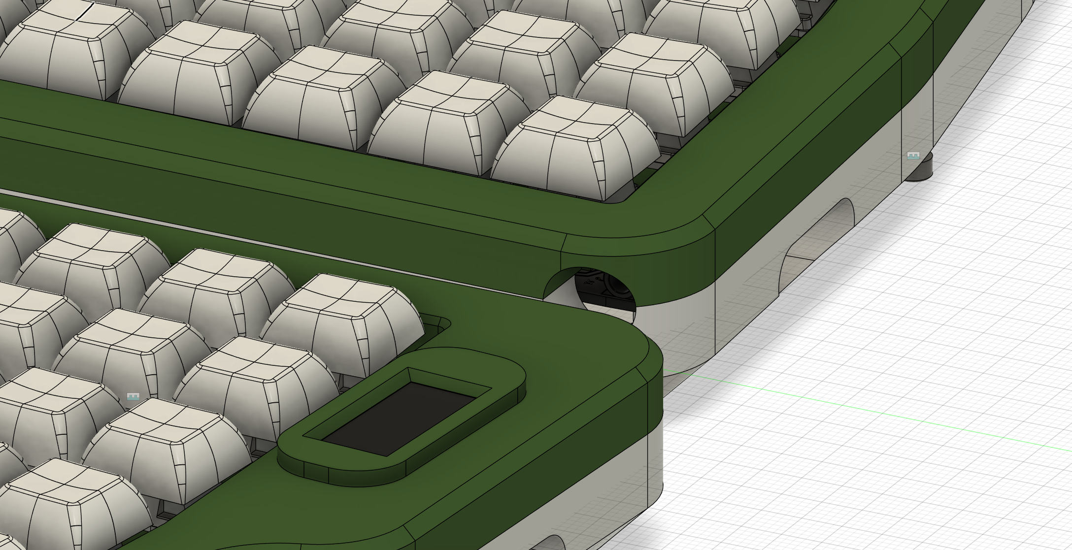
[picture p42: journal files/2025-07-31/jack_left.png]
  
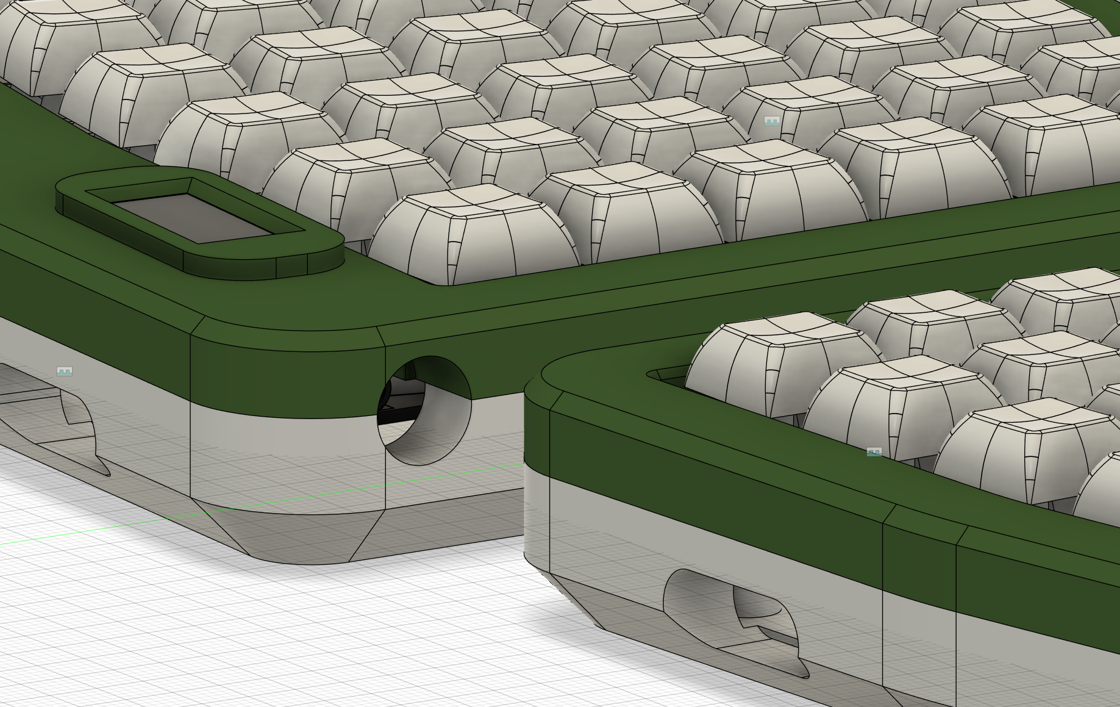
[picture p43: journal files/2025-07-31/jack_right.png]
  
</p>

### Session 4 (1h) finalising firmware, creation production files

The last step now was to recheck everything and create the required files for production. Besides that the project als need to fullfill the hackclub requirements for a submission. I also decided to make some cool renders to show off my keyboard that took so long to desing. Rotation the footprints in KiCad was anabsolute nightmare.

Besides all of that I think I can submit my project now. I have check multiple times if I have everything.

<p float="left">
  
    
</p>
<p float="left">
  
  
</p>
<p float="left">
  
  
</p>

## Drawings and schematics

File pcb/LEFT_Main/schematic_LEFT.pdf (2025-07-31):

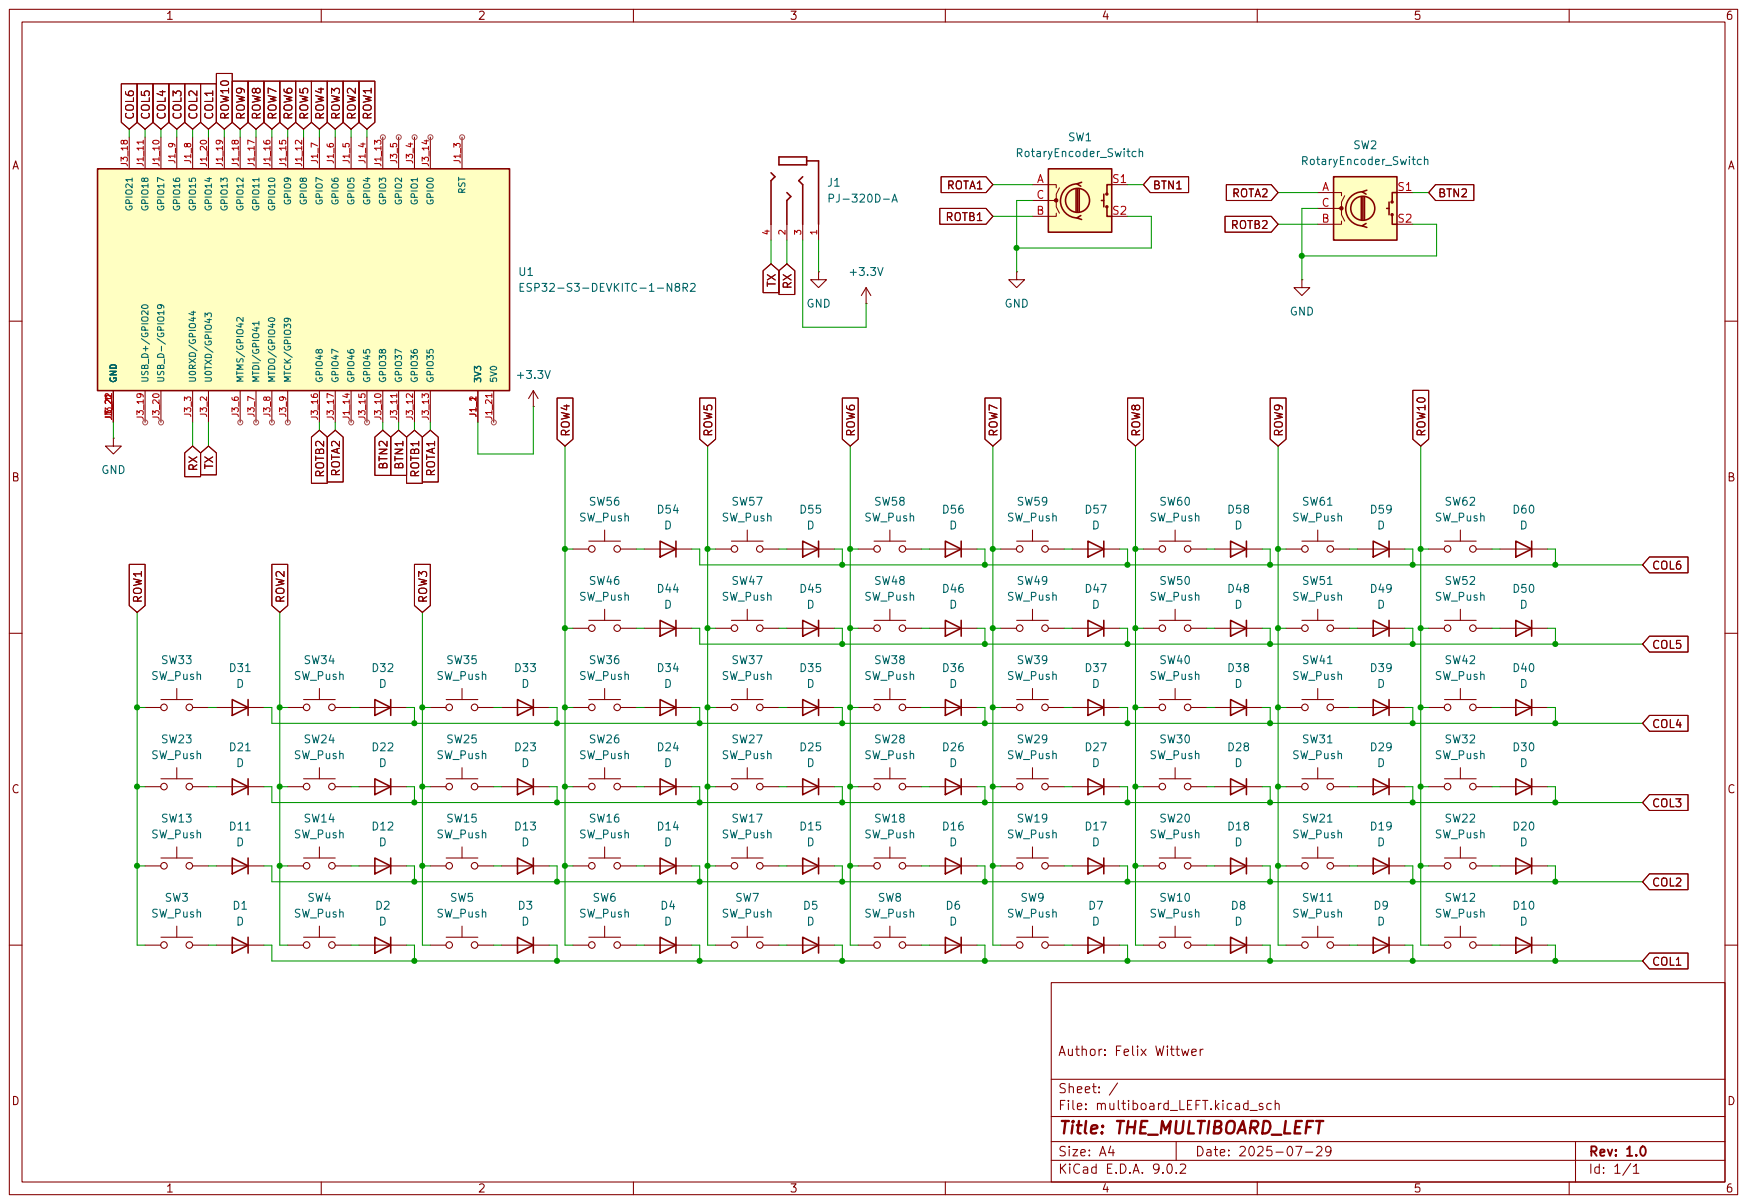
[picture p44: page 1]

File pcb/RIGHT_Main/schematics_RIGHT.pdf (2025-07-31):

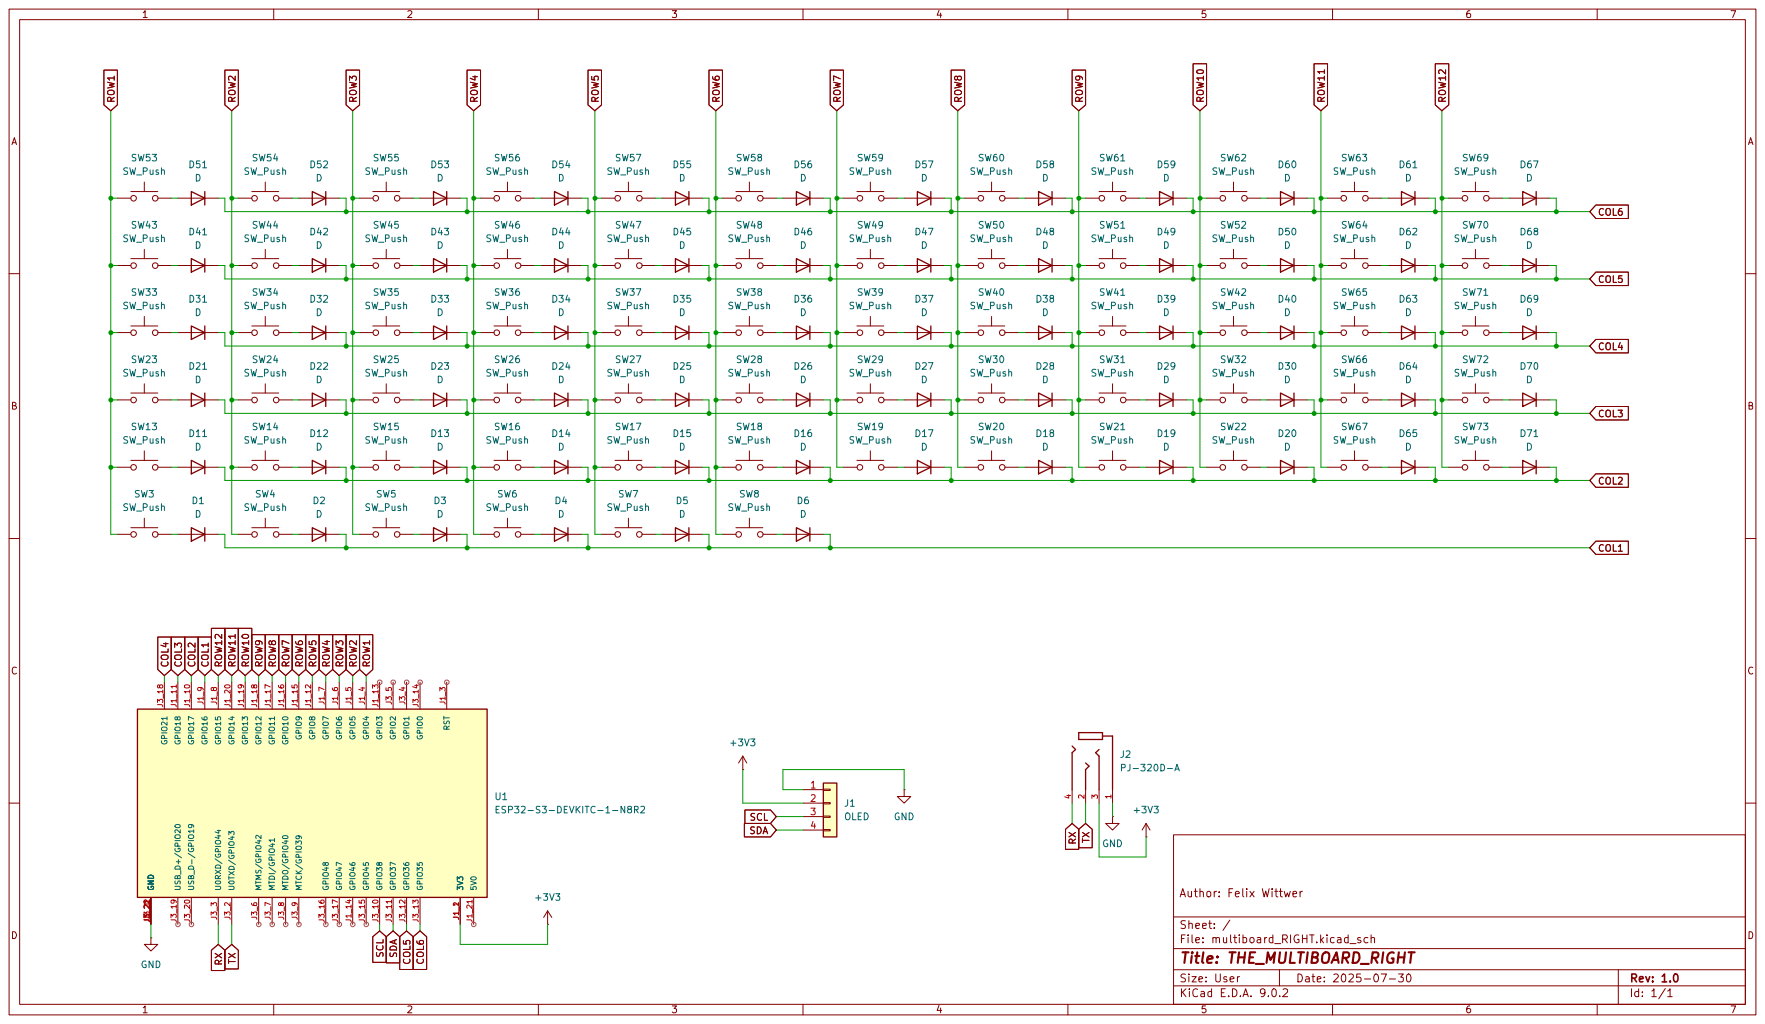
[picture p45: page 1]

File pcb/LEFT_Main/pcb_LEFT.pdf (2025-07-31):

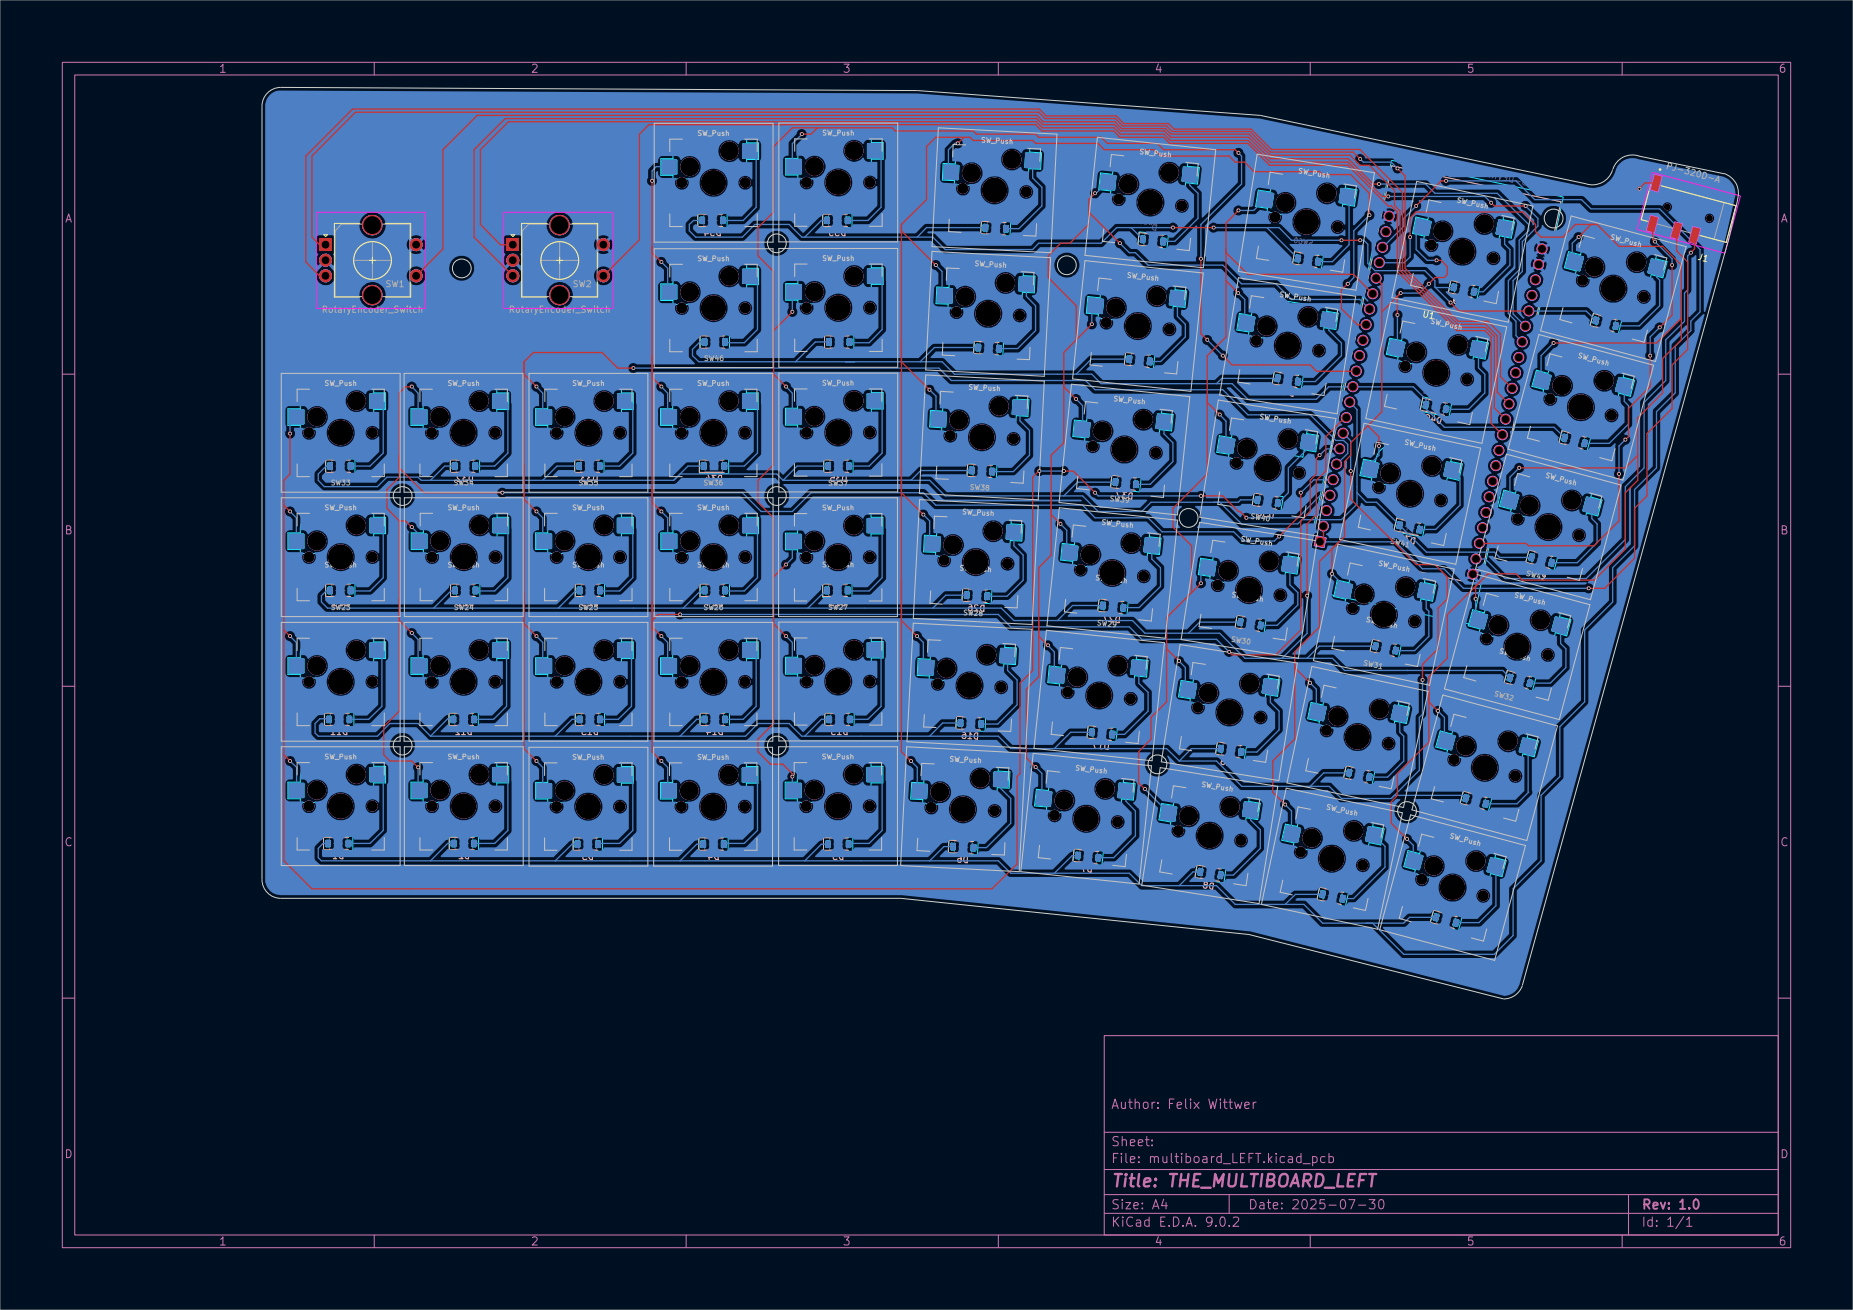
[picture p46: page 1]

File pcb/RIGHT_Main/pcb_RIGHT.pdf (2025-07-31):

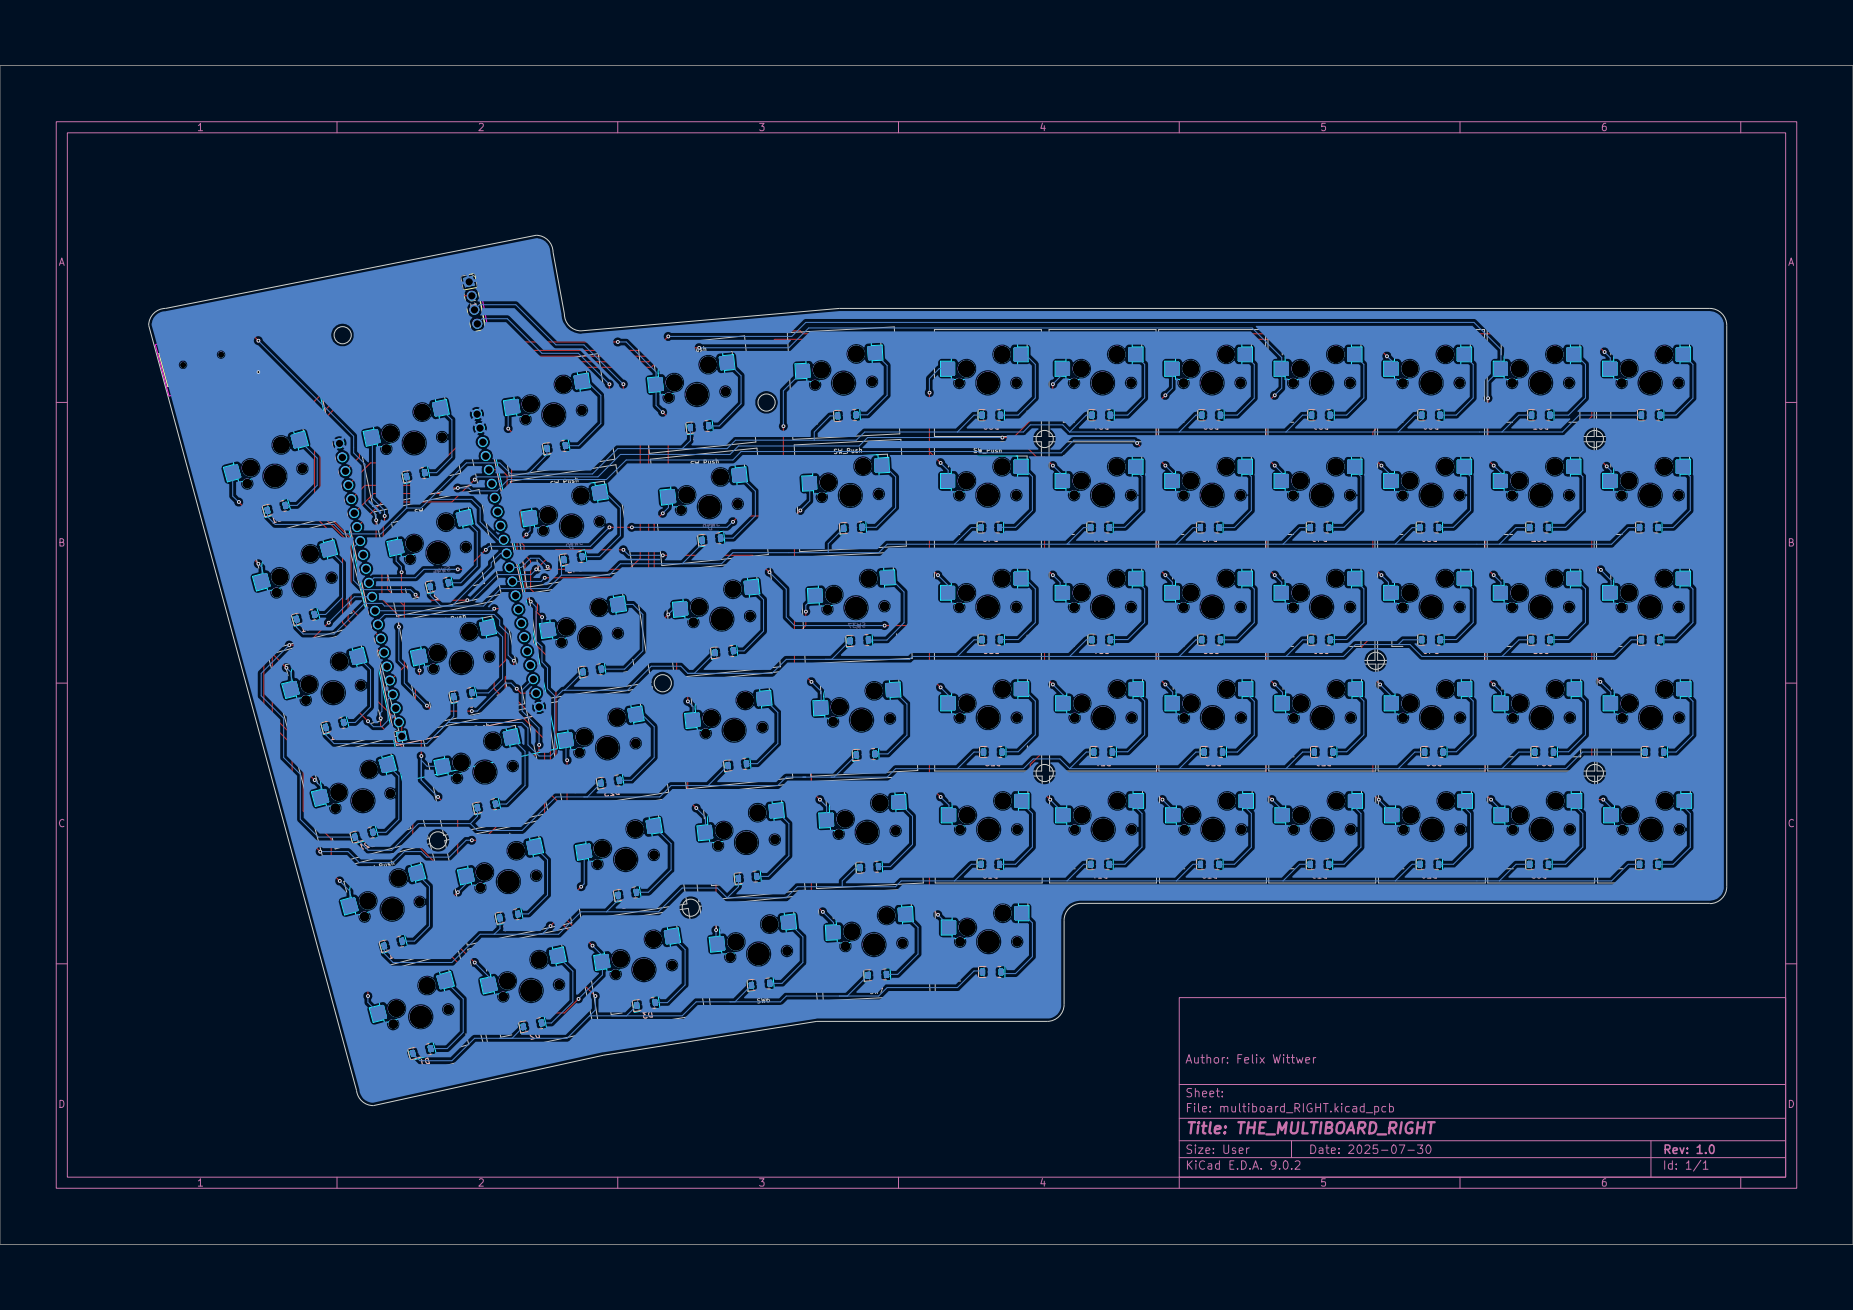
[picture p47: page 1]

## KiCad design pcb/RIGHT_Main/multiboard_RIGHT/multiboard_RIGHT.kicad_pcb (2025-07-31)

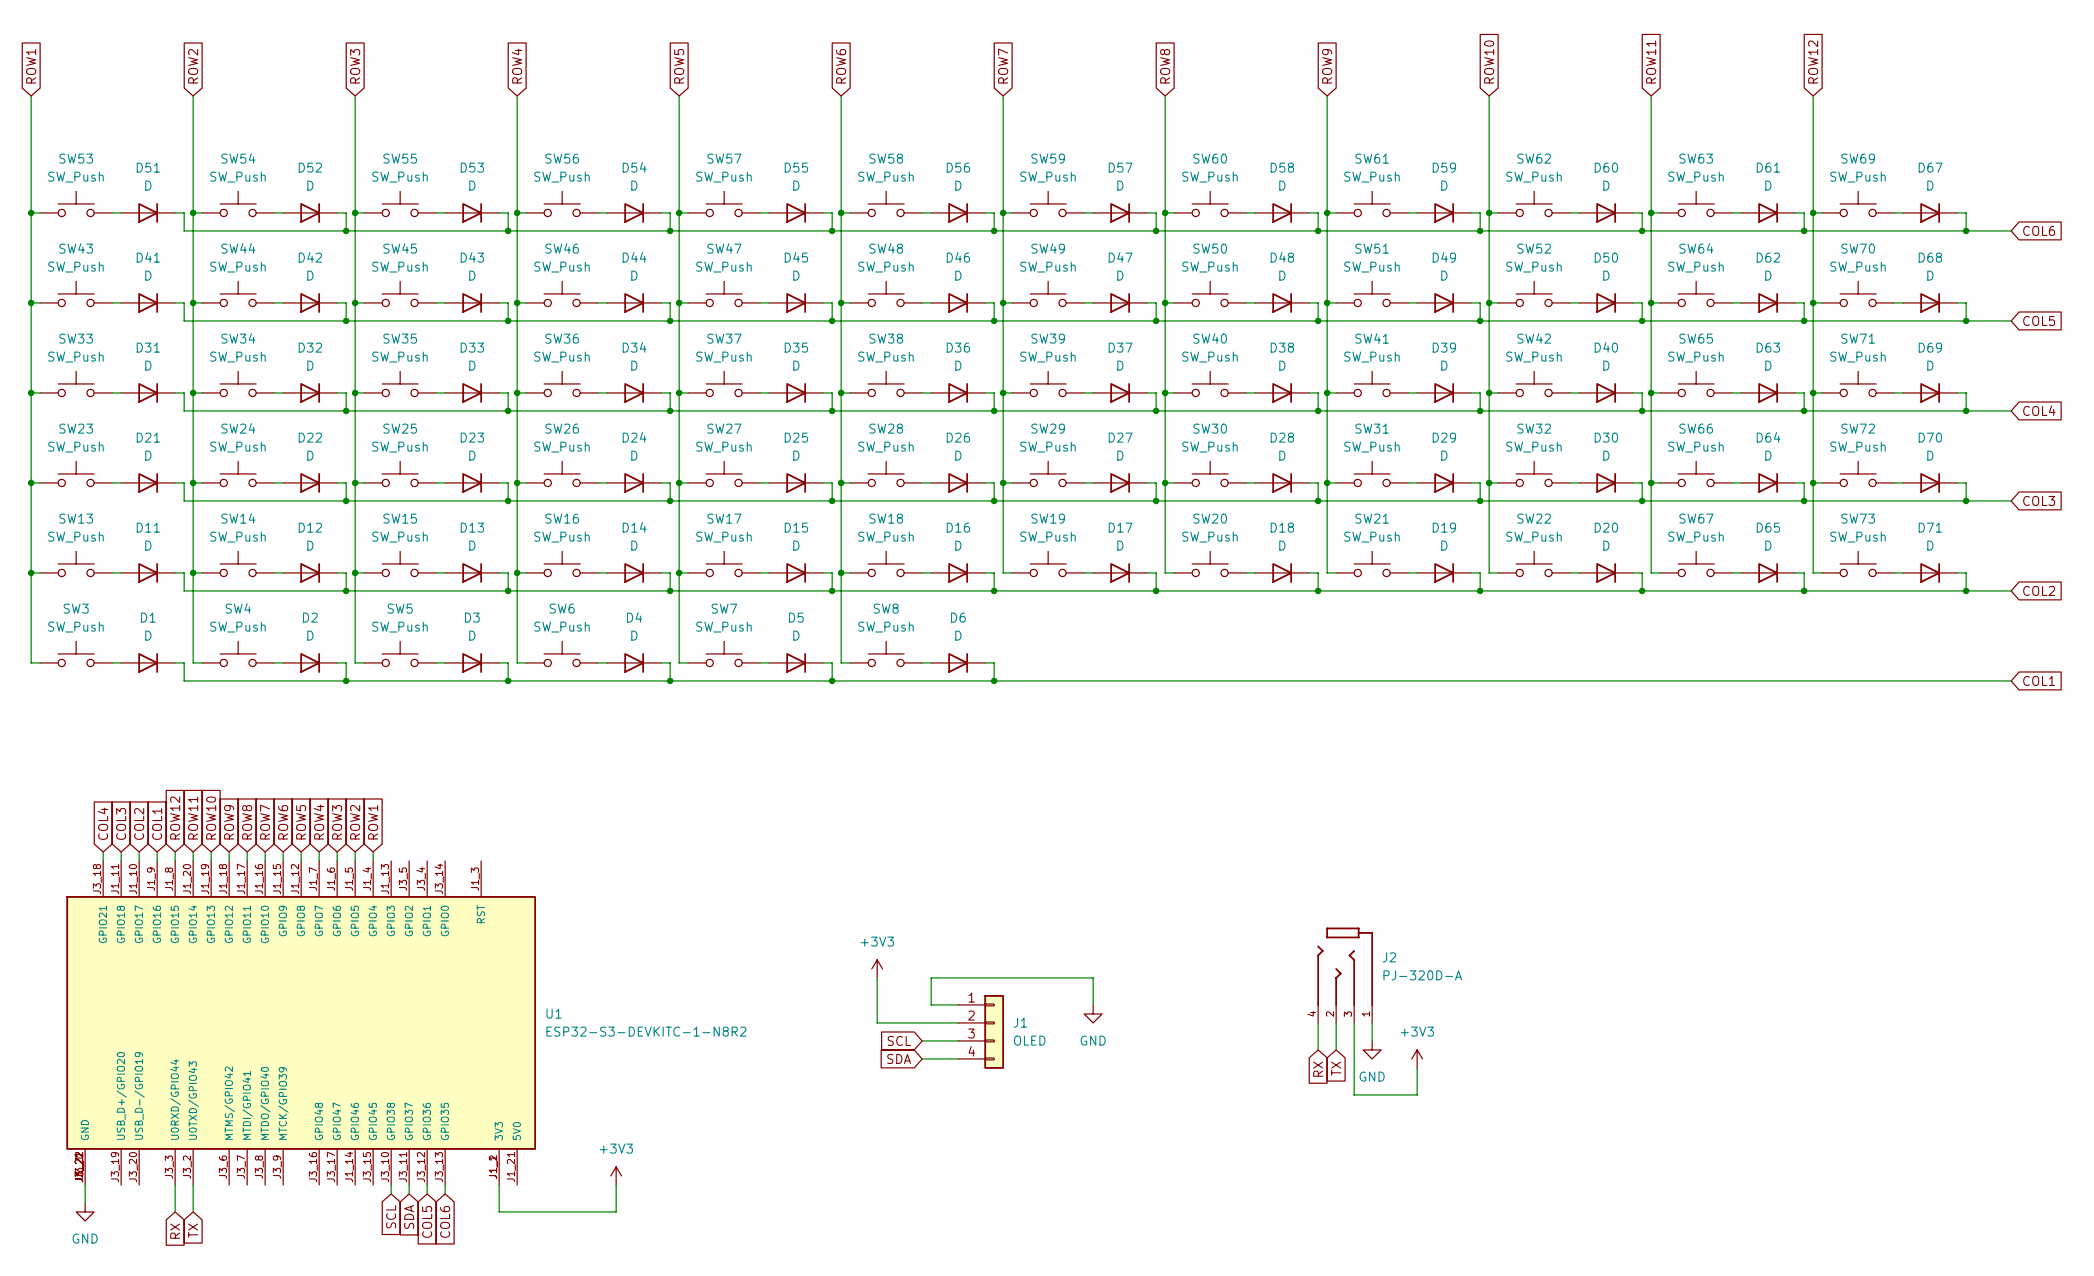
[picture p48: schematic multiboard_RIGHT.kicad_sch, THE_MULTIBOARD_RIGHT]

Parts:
D1, D2, D3, D4, D5, D6, D11, D12, D13, D14, D15, D16, D17, D18, D19, D20, D21, D22, D23, D24, D25, D26, D27, D28, D29, D30, D31, D32, D33, D34, D35, D36, D37, D38, D39, D40, D41, D42, D43, D44, D45, D46, D47, D48, D49, D50, D51, D52, D53, D54, D55, D56, D57, D58, D59, D60, D61, D62, D63, D64, D65, D67, D68, D69, D70, D71: D; D_SOD-123
J1: OLED; PinSocket_1x04_P2.54mm_Vertical
J2: PJ-320D-A; HRO_PJ-320D-A; PARTREV B
SW3, SW4, SW5, SW6, SW7, SW8, SW13, SW14, SW15, SW16, SW17, SW18, SW19, SW20, SW21, SW22, SW23, SW24, SW25, SW26, SW27, SW28, SW29, SW30, SW31, SW32, SW33, SW34, SW35, SW36, SW37, SW38, SW39, SW40, SW41, SW42, SW43, SW44, SW45, SW46, SW47, SW48, SW49, SW50, SW51, SW52, SW53, SW54, SW55, SW56, SW57, SW58, SW59, SW60, SW61, SW62, SW63, SW64, SW65, SW66, SW67, SW69, SW70, SW71, SW72, SW73: SW_Push; MX-Hotswap-1U
U1: ESP32-S3-DEVKITC-1-N8R2; XCVR_ESP32-S3-DEVKITC-1-N8R2; PARTREV V1

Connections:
+3V3: J1.2, J2.3, U1.J1_1 (3V3), U1.J1_2 (3V3)
COL1: D1.1 (K), D2.1 (K), D3.1 (K), D4.1 (K), D5.1 (K), D6.1 (K), U1.J1_9 (GPIO16)
COL2: D11.1 (K), D12.1 (K), D13.1 (K), D14.1 (K), D15.1 (K), D16.1 (K), D17.1 (K), D18.1 (K), D19.1 (K), D20.1 (K), D65.1 (K), D71.1 (K), U1.J1_10 (GPIO17)
COL3: D21.1 (K), D22.1 (K), D23.1 (K), D24.1 (K), D25.1 (K), D26.1 (K), D27.1 (K), D28.1 (K), D29.1 (K), D30.1 (K), D64.1 (K), D70.1 (K), U1.J1_11 (GPIO18)
COL4: D31.1 (K), D32.1 (K), D33.1 (K), D34.1 (K), D35.1 (K), D36.1 (K), D37.1 (K), D38.1 (K), D39.1 (K), D40.1 (K), D63.1 (K), D69.1 (K), U1.J3_18 (GPIO21)
COL5: D41.1 (K), D42.1 (K), D43.1 (K), D44.1 (K), D45.1 (K), D46.1 (K), D47.1 (K), D48.1 (K), D49.1 (K), D50.1 (K), D62.1 (K), D68.1 (K), U1.J3_12 (GPIO36)
COL6: D51.1 (K), D52.1 (K), D53.1 (K), D54.1 (K), D55.1 (K), D56.1 (K), D57.1 (K), D58.1 (K), D59.1 (K), D60.1 (K), D61.1 (K), D67.1 (K), U1.J3_13 (GPIO35)
GND: J1.1, J2.1, U1.J1_22 (GND), U1.J3_1 (GND), U1.J3_21 (GND), U1.J3_22 (GND)
unnamed: D1.2 (A), SW3.2
unnamed: D2.2 (A), SW4.2
unnamed: D3.2 (A), SW5.2
unnamed: D4.2 (A), SW6.2
unnamed: D5.2 (A), SW7.2
unnamed: D6.2 (A), SW8.2
unnamed: D11.2 (A), SW13.2
unnamed: D12.2 (A), SW14.2
unnamed: D13.2 (A), SW15.2
unnamed: D14.2 (A), SW16.2
unnamed: D15.2 (A), SW17.2
unnamed: D16.2 (A), SW18.2
unnamed: D17.2 (A), SW19.2
unnamed: D18.2 (A), SW20.2
unnamed: D19.2 (A), SW21.2
unnamed: D20.2 (A), SW22.2
unnamed: D21.2 (A), SW23.2
unnamed: D22.2 (A), SW24.2
unnamed: D23.2 (A), SW25.2
unnamed: D24.2 (A), SW26.2
unnamed: D25.2 (A), SW27.2
unnamed: D26.2 (A), SW28.2
unnamed: D27.2 (A), SW29.2
unnamed: D28.2 (A), SW30.2
unnamed: D29.2 (A), SW31.2
unnamed: D30.2 (A), SW32.2
unnamed: D31.2 (A), SW33.2
unnamed: D32.2 (A), SW34.2
unnamed: D33.2 (A), SW35.2
unnamed: D34.2 (A), SW36.2
unnamed: D35.2 (A), SW37.2
unnamed: D36.2 (A), SW38.2
unnamed: D37.2 (A), SW39.2
unnamed: D38.2 (A), SW40.2
unnamed: D39.2 (A), SW41.2
unnamed: D40.2 (A), SW42.2
unnamed: D41.2 (A), SW43.2
unnamed: D42.2 (A), SW44.2
unnamed: D43.2 (A), SW45.2
unnamed: D44.2 (A), SW46.2
unnamed: D45.2 (A), SW47.2
unnamed: D46.2 (A), SW48.2
unnamed: D47.2 (A), SW49.2
unnamed: D48.2 (A), SW50.2
unnamed: D49.2 (A), SW51.2
unnamed: D50.2 (A), SW52.2
unnamed: D51.2 (A), SW53.2
unnamed: D52.2 (A), SW54.2
unnamed: D53.2 (A), SW55.2
unnamed: D54.2 (A), SW56.2
unnamed: D55.2 (A), SW57.2
unnamed: D56.2 (A), SW58.2
unnamed: D57.2 (A), SW59.2
unnamed: D58.2 (A), SW60.2
unnamed: D59.2 (A), SW61.2
unnamed: D60.2 (A), SW62.2
unnamed: D61.2 (A), SW63.2
unnamed: D62.2 (A), SW64.2
unnamed: D63.2 (A), SW65.2
unnamed: D64.2 (A), SW66.2
unnamed: D65.2 (A), SW67.2
unnamed: D67.2 (A), SW69.2
unnamed: D68.2 (A), SW70.2
unnamed: D69.2 (A), SW71.2
unnamed: D70.2 (A), SW72.2
unnamed: D71.2 (A), SW73.2
ROW1: SW3.1, SW13.1, SW23.1, SW33.1, SW43.1, SW53.1, U1.J1_4 (GPIO4)
ROW2: SW4.1, SW14.1, SW24.1, SW34.1, SW44.1, SW54.1, U1.J1_5 (GPIO5)
ROW3: SW5.1, SW15.1, SW25.1, SW35.1, SW45.1, SW55.1, U1.J1_6 (GPIO6)
ROW4: SW6.1, SW16.1, SW26.1, SW36.1, SW46.1, SW56.1, U1.J1_7 (GPIO7)
ROW5: SW7.1, SW17.1, SW27.1, SW37.1, SW47.1, SW57.1, U1.J1_12 (GPIO8)
ROW6: SW8.1, SW18.1, SW28.1, SW38.1, SW48.1, SW58.1, U1.J1_15 (GPIO9)
ROW7: SW19.1, SW29.1, SW39.1, SW49.1, SW59.1, U1.J1_16 (GPIO10)
ROW8: SW20.1, SW30.1, SW40.1, SW50.1, SW60.1, U1.J1_17 (GPIO11)
ROW9: SW21.1, SW31.1, SW41.1, SW51.1, SW61.1, U1.J1_18 (GPIO12)
ROW10: SW22.1, SW32.1, SW42.1, SW52.1, SW62.1, U1.J1_19 (GPIO13)
ROW11: SW63.1, SW64.1, SW65.1, SW66.1, SW67.1, U1.J1_20 (GPIO14)
ROW12: SW69.1, SW70.1, SW71.1, SW72.1, SW73.1, U1.J1_8 (GPIO15)
RX: J2.4, U1.J3_3 (U0RXD/GPIO44)
SCL: J1.3, U1.J3_10 (GPIO38)
SDA: J1.4, U1.J3_11 (GPIO37)
TX: J2.2, U1.J3_2 (U0TXD/GPIO43)

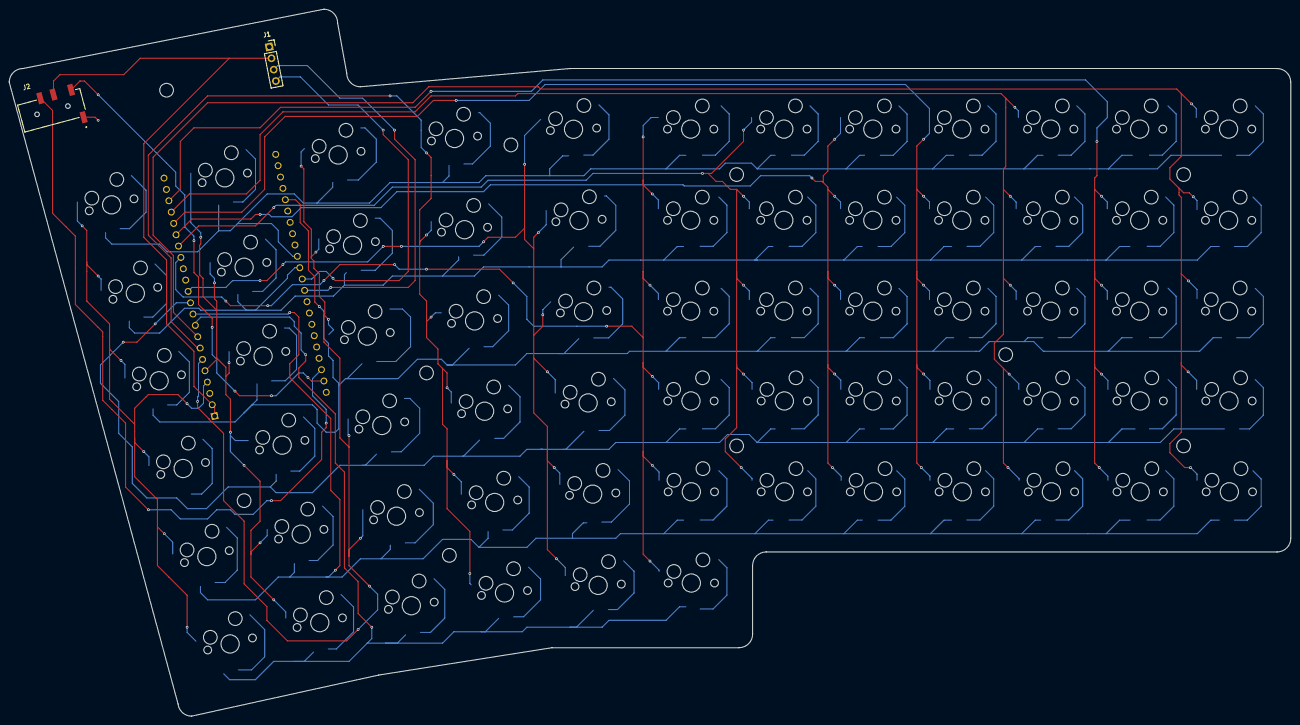
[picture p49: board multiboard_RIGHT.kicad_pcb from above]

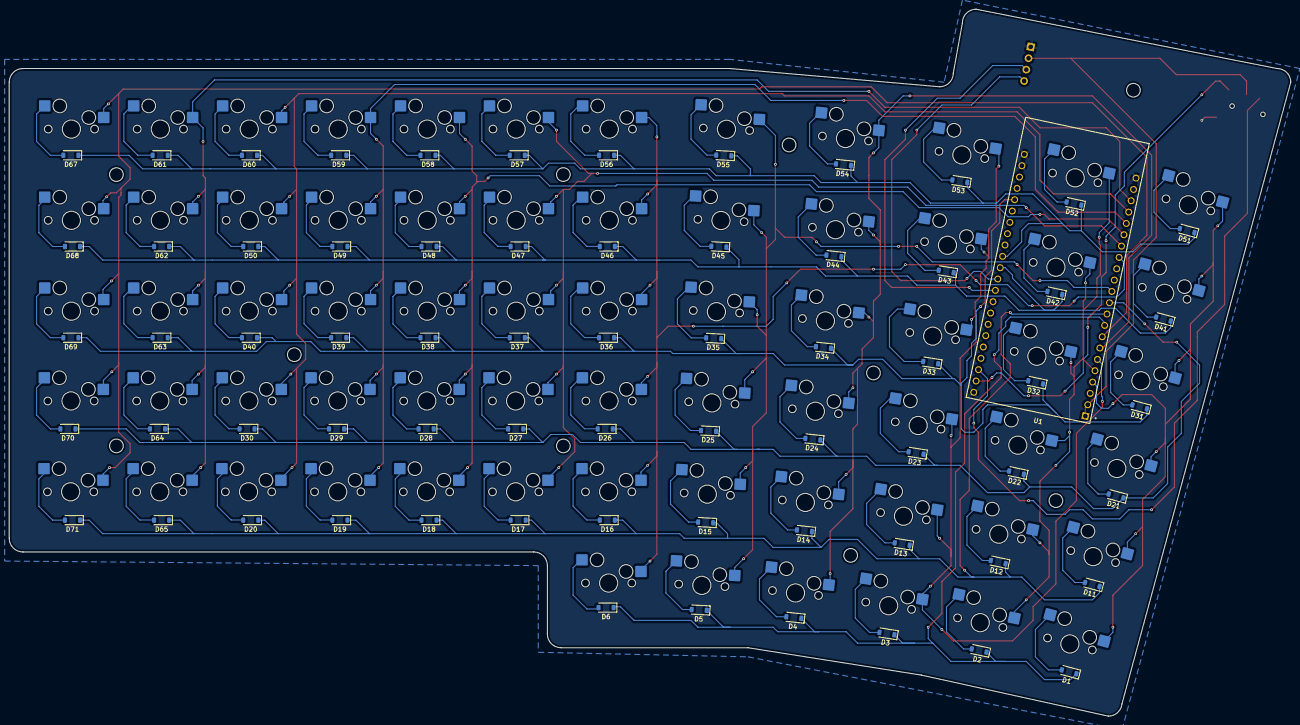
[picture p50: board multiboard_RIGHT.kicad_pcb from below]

Board: 2 copper layers, 281.0 x 155.0 mm, 135 parts (133 on the bottom side), 90 nets.

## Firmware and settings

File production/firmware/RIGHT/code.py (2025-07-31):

import board
from kmk.kmk_keyboard import KMKKeyboard
from kmk.scanners import DiodeOrientation
from kmk.keys import KC
from kmk.modules.split import Split, SplitSide
from kmk.modules.steno import Steno, StenoKey
from kmk.modules.layers import Layers
from kmk.modules.oled import OLED
from kmk.modules.oled import OledDisplayMode
from kmk.extensions.ble import BLE

keyboard = KMKKeyboard()

ble = BLE(name="TheMultiboard")
keyboard.extensions.append(ble)
keyboard.persistent_storage = True


keyboard.col_pins = (
    board.IO04, board.IO05, board.IO06, board.IO07,
    board.IO08, board.IO09, board.IO10, board.IO11, 
    board.IO12, board.IO13, board.IO14, board.IO15
)
keyboard.row_pins = (
    board.IO16, board.IO17, board.IO18, board.IO21,
    board.IO35, board.IO36
)
keyboard.diode_orientation = DiodeOrientation.ROW2COL

keyboard.modules.append(Layers())

oled = OLED(
    oled_addr=0x3C,
    sda=board.IO37,
    scl=board.IO38,
    i2c_bus=1,
    display_mode=OledDisplayMode.SPLIT,
    flip=False,
)
keyboard.modules.append(oled)

split = Split(
    split_side=SplitSide.RIGHT,
    uart_tx=board.IO43,
    uart_rx=board.IO44,
    use_pio=True,
)
keyboard.modules.append(split)

keyboard.modules.append(Steno())

keyboard.keymap = [
    [
        KC.F8, KC.F9, KC.F10, KC.F11, KC.F12, KC.PSCR, KC.INS, KC.DEL, KC.ASTR, KC.NLCK, KC.ESC, None
        KC.N7, KC.N8, KC.N9, KC.N0, KC.MINS, KC.EQL, KC.BSPC, KC.NUBS, KC.SLSH, KC.N7, KC.N8, KC.N9
        KC.Z, KC.U, KC.I, KC.O, KC.P, KC.UDIA, KC.PLUS, KC.ENT, KC.PPLS, KC.N4, KC.N5, KC.N6
        KC.H, KC.J, KC.K, KC.L, KC.ODIA, KC.ADIA, KC.RSFT, KC.UP, KC.MINS, KC.N1, KC.N2, KC.N3
        KC.B, KC.N, KC.M, KC.COMM, KC.DOT, KC.MINS, KC.LEFT, KC.DOWN, KC.RIGHT, KC.N0, KC.COMM, KC.PENT
        KC.SPC, KC.SPC, KC.SPC, KC.RALT, KC.MPRV, KC.RCTL, None, None, None, None, None, None,
    ],
    [
        None, None, None, None, None, None, None, None, None, None, None, None,
        None, None, None, None, None, None, None, None, None, None, None, None,
        StenoKey('*'), StenoKey('F-'), StenoKey('P-'), StenoKey('L-'), StenoKey('T-'), StenoKey('D-'), None, None, None, None, None, None,
        StenoKey('*'), StenoKey('R-'), StenoKey('B-'), StenoKey('G-'), StenoKey('S-'), StenoKey('Z-'), None, None,None, None, None, None,
        None, None, None, None, None, None, None, None, None, None, None, None,
        StenoKey('E-'), StenoKey('U-'), None, None, None, None, None, None, None, None, None, None,
    ],
]

if __name__ == '__main__':
    keyboard.go()

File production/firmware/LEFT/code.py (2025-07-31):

import board
from kmk.kmk_keyboard import KMKKeyboard
from kmk.scanners import DiodeOrientation
from kmk.keys import KC
from kmk.modules.split import Split, SplitSide
from kmk.modules.encoder import EncoderHandler
from kmk.modules.steno import Steno, StenoKey
from kmk.modules.layers import Layers
from kmk.extensions.media_keys import MediaKeys
from kmk.handlers.sequences import simple_key_sequence, macro

keyboard = KMKKeyboard()

keyboard.col_pins = (
    board.IO04, board.IO05, board.IO06, board.IO07, board.IO08,
    board.IO09, board.IO10, board.IO11, board.IO12, board.IO13
)
keyboard.row_pins = (
    board.I14, board.I15, board.I16,
    board.I17, board.I18, board.I21,
)
keyboard.diode_orientation = DiodeOrientation.ROW2COL

keyboard.modules.append(Layers())

split = Split(
    split_side=SplitSide.LEFT,
    uart_tx=board.IO43,
    uart_rx=board.IO44,
    use_pio=True,
)
keyboard.modules.append(split)

encoder_handler = EncoderHandler()
encoder_handler.pins = [
    (board.IO35, board.IO36),
    (board.IO47, board.IO48),
]
encoder_handler.map = [
    ((KC.VOLD, KC.VOLU), (KC.LEFT, KC.RIGHT)),
]
keyboard.modules.append(encoder_handler)

keyboard.modules.append(Steno())
keyboard.extensions.append(MediaKeys())

M00 = KC.NO
M01 = macro(simple_key_sequence((KC.LCTL, KC.C)))
M02 = KC.NO
M03 = KC.NO
M04 = macro(simple_key_sequence((KC.LCTL, KC.V)))  # Paste
M05 = macro(simple_key_sequence((KC.LCTL, KC.Z)))  # Undo
M06 = macro(simple_key_sequence((KC.LCTL, KC.Y)))  # Redo
M07 = macro(simple_key_sequence((KC.LCTL, KC.X)))  # Cut
M08 = KC.NO
M09 = KC.NO
M10 = KC.NO
M11 = KC.NO
M12 = KC.NO
M13 = KC.NO
M14 = KC.NO
M15 = KC.NO

keyboard.keymap = [
    [
        None, None, None, KC.TG(1), KC.F1, KC.F2, KC.F3, KC.F4, KC.F5, KC.F6,
        None, None, None, KC.ESC, KC.N1, KC.N2, KC.N3, KC.N4, KC.N5, KC.N6,
        M00, M01, M02, M03, KC.GRV, KC.Q, KC.W, KC.E, KC.R, KC.T,
        M04, M05, M06, M07, KC.TAB, KC.A, KC.S, KC.D, KC.F, KC.G,
        M08, M09, M10, M11, KC.LSFT, KC.LSFT, KC.Y, KC.X, KC.C, KC.V,
        M12, M13, M14, M15, KC.LCTL, KC.RGUI, KC.LALT, KC.SPC, KC.SPC, KC.SPC,
    ],
    [
        None, None, None, KC.TG(1), None, None, None, None, None, None,
        None, None, None, None, None, None, None, None, None, None,
        None, None, None, None, None, StenoKey('S-'), StenoKey('T-'), StenoKey('P-'), StenoKey('H-'), StenoKey('*'),
        None, None, None, None, None, StenoKey('S-'), StenoKey('K-'), StenoKey('W-'), StenoKey('R-'), StenoKey('*'),
        None, None, None, None, None, None, None, None, None, None,
        None, None, None, None, None, None, None, StenoKey('A-'), StenoKey('O-'), StenoKey('*'),
    ],
]

if __name__ == '__main__':
    keyboard.go()

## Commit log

2025-07-29 add schematics for LEFT PCB
    [Gateron-KS33-Socket.step, Kailh-Choc-Socket-CPG135001S30.step, MX-Hotswap-Socket.step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]
2025-07-30 finishing LEFT PCB
    [multiboard_LEFT.kicad_pcb, multiboard_LEFT.kicad_sch]
2025-07-30 finish left and right main pcbs
    [Gateron-KS33-Socket.step, Kailh-Choc-Socket-CPG135001S30.step, MX-Hotswap-Socket.step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]
2025-07-31 add cad files
    [Gateron-KS33-Socket.step, Kailh-Choc-Socket-CPG135001S30.step, MX-Hotswap-Socket.step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]
2025-07-31 add headphone jack
    [PJ-320D-A.step, multiboard_LEFT.kicad_pcb, multiboard_LEFT.kicad_sch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]
2025-07-31 getting ready for submission - add production files - refine BOM - make README beautiful
    [BOM.csv, left_bottom.step, left_bottom.stl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]
